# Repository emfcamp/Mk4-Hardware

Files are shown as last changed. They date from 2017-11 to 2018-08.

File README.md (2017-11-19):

Hardware
========

Hardware for the TiLDA Mkδ Badge for [Electromagnetic Field
2018](https://www.emfcamp.org).

Key Specs
---------
* TBD
*
*

License
-------
Copyright Electromagnetic Field Ltd. 2017

This documentation describes Open Hardware and is licensed under the
CERN OHL v. 1.2.  You may redistribute and modify this documentation
under the terms of the CERN OHL v.1.2. (http://ohwr.org/cernohl or the
LICENSE file in this repository). This documentation is distributed
WITHOUT ANY EXPRESS OR IMPLIED WARRANTY, INCLUDING OF MERCHANTABILITY,
SATISFACTORY QUALITY AND FITNESS FOR A PARTICULAR PURPOSE. Please see
the CERN OHL v.1.2 for applicable conditions.

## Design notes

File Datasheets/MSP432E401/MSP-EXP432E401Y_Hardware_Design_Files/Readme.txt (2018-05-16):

MSP-EXP432E401Y Hardware Design Files v1.00.00
Texas Instruments, Inc.

********************************************************************************
Welcome to the MSP-EXP432E401Y LaunchPad!
********************************************************************************

In this package, you will find hardware design files that can help you quickly
get started on developing your own project.

Available in the 'Hardware' folder are the complete board schematic and layout,
bill of material and Gerber files. This board was designed using Altium.

You can also find various web links in the 'Documentation' folder pointing to
the Tool Page, Quick Start Guide, and User's Guide.

For more resources, be sure to visit www.ti.com/tool/msp-exp432e401y

********************************************************************************
Revision History
********************************************************************************
Ver 1.00.00 - November 2nd, 2017
- Initial Release of Rev1.0 PCB

********************************************************************************
Project File Listing
********************************************************************************
|--Documentation                      : Folder containing links to more resources
|--Hardware                           : Folder containing hardware design files,
                                        bill of material and gerber files
|--Readme.txt                         : This file

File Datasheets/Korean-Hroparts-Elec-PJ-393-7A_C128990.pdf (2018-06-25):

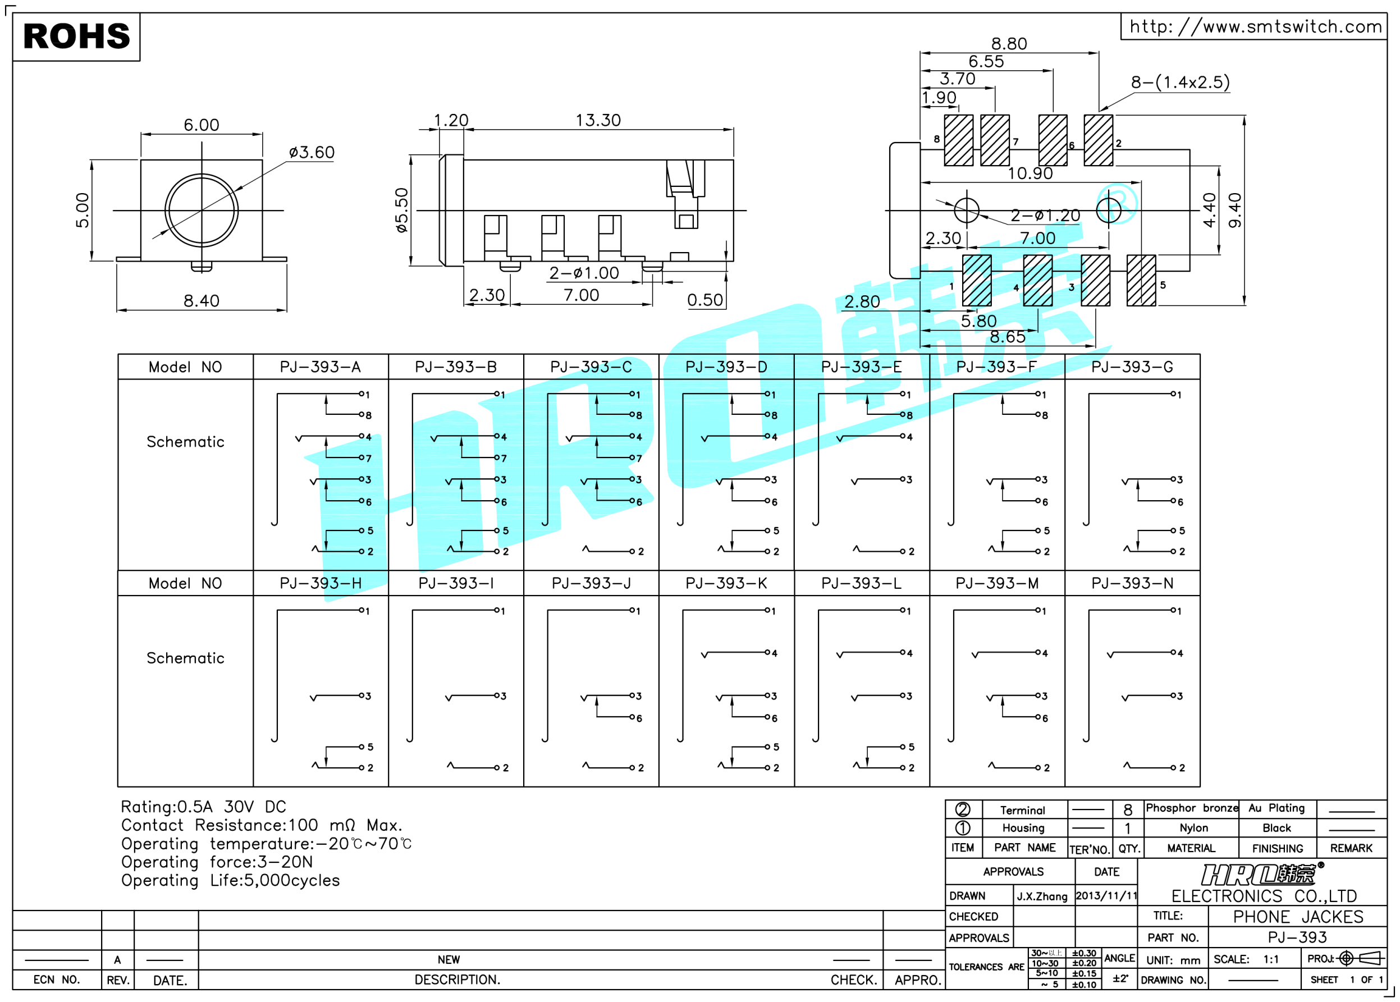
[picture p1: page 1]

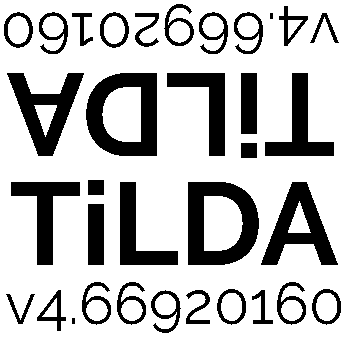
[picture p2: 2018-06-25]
Images/TiLDA v.466920160.bmp

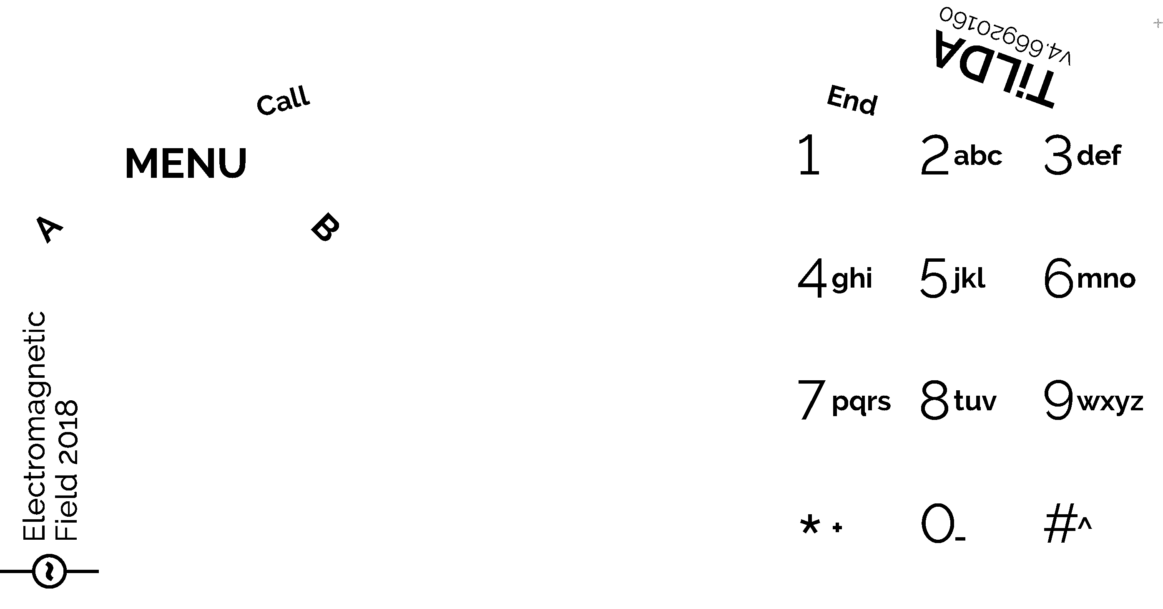
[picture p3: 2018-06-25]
Images/Mk4 Prototype a lwk.bmp

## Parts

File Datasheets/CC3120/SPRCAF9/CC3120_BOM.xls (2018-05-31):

Filename: | WCS001ABOM.xls
Variant: | None
Generated: | 11/30/2016 1:37:10 PM
 |  | CC3120-BOOST
Designator | Quantity | Value | Description | PackageReference | PartNumber | Manufacturer | Alternate PartNumber | Alternate Manufacturer
!PCB1 | 1 |  | Printed Circuit Board |  | WCS001 | Any | - | -
C1, C22, C24 | 3 | 10pF | CAP, CERM, 10 pF, 50 V, +/- 5%, C0G/NP0, 0402 | 0402 | 500R07S100JV4T | Johanson Technology
C2 | 1 | 0.5pF | CAP, CERM, 0.5 pF, 50 V, +/- 20%, C0G/NP0, 0402 | 0402 | GRM1555C1HR50BA01D | MuRata
C3, C5, C7, C8, C9, C10, C14, C15, C17, C18, C23, C27 | 12 | 0.1uF | CAP, CERM, 0.1 µF, 10 V, +/- 10%, X5R, 0402 | 0402 | C1005X5R1A104K050BA | TDK
C4, C16, C21 | 3 | 10uF | CAP, CERM, 10 µF, 6.3 V, +/- 20%, X5R, 0603 | 0603 | GRM188R60J106ME47D | MuRata
C6 | 1 | 1uF | CAP, CERM, 1 µF, 10 V, +/- 10%, X5R, 0402 | 0402 | C1005X5R1A105K050BB | TDK
C11, C12, C13 | 3 | 4.7uF | CAP, CERM, 4.7 µF, 6.3 V, +/- 20%, X5R, 0402 | 0402 | C1005X5R0J475M050BC | TDK
C19, C20 | 2 | 22uF | CAP, CERM, 22 µF, 4 V, +/- 20%, X5R, 0603 | 0603 | C1608X5R0G226M080AA | TDK
C25, C26 | 2 | 6.2pF | CAP, CERM, 6.2 pF, 50 V, +/- 5%, C0G/NP0, 0402 | 0402 | GRM1555C1H6R2CA01D | MuRata
C28 | 1 | 15pF | CAP, CERM, 15 pF, 50 V, +/- 5%, C0G/NP0, 0402 | 0402 | GRM1555C1H150JA01D | MuRata
C29, C32 | 2 | 10uF | CAP, CERM, 10 µF, 10 V, +/- 10%, X5R, 0805 | 0805 | GRM21BR61A106KE19L | MuRata
C30, C31 | 2 | 100uF | CAP, CERM, 100 µF, 6.3 V, +/- 20%, X5R, 1206 | 1206 | GRM31CR60J107ME39L | MuRata
C33 | 1 | 1000pF | CAP, CERM, 1000 pF, 50 V, +/- 10%, X5R, 0603 | 0603 | GRM188R61H102KA01D | MuRata
D1, D2 | 2 | 30V | Diode, Schottky, 30 V, 1 A, SOD-123 | SOD-123 | MBR130T1G | ON Semiconductor
D3 | 1 | Red | LED, Red, SMD | LED, 1.6x.8x.8mm | SML-311UTT86 | Rohm
D4 | 1 | Red | LED, Red, SMD | LED_0603 | 150060RS75000 | Wurth Elektronik
D5 | 1 | Green | LED, Green, SMD | LED_0603 | 150060GS75000 | Wurth Elektronik
D6 | 1 | Yellow | LED, Yellow, SMD | LED_0603 | 150060YS75000 | Wurth Elektronik eiSos
D7 | 1 | 45V | Diode, Schottky, 45 V, 0.03 A, 0603 Diode | 0603 Diode | CD0603-B00340 | Bourns
E1 | 1 |  | ANT BLUETOOTH W-LAN ZIGBEE WIMAX, SMD | 3.2x1.6mm | AH316M245001-T | Taiyo Yuden
FID1, FID2, FID3, FID4, FID5, FID6 | 6 |  | Fiducial mark. There is nothing to buy or mount. | Fiducial | N/A | N/A
FL1 | 1 | 1.02 dB | Multilayer Chip Band Pass Filter For 2.4GHz W-LAN/Bluetooth, SMD | 2x1.25mm | DEA202450BT-1294C1-H | TDK
J1 | 1 |  | Connector, Ultra-Mini Coaxial, SMD | Ultra small CO-AX SMD | U.FL-R-SMT-1 | Hirose Electric Co. Ltd.
J2 | 1 |  | Coaxial Connectors with Switch, 50 Ohm, SMD | Coaxial Connector with Switch | MM8030-2610RJ3 | MuRata
J4 | 1 |  | Header, 50mil, 3x2, Gold, TH | Header, 3x2, 1.27mm, TH | GRPB032VWVN-RC | Sullins Connector Solutions
J5 | 1 |  | Header, 50mil, 4x1, Gold, TH | TH, Header, 1.27 mm, 4x1, Straight | GRPB041VWVN-RC | Sullins Connector Solutions
J6 | 1 |  | Connector, Receptacle, Micro-USB Type B, R/A, Bottom Mount SMT | Micro USB receptacle | 105017-0001 | Molex
J7 | 1 |  | Header, 100mil, 3x1, Gold, TH | 3x1 Header | TSW-103-07-G-S | Samtec
J8 | 1 |  | Header, 100mil, 2x1, Gold, TH | Header, 2.54mm, 2x1, TH | HMTSW-102-07-G-S-240 | Samtec
L1 | 1 | 3.3nH | Inductor, Multilayer, Air Core, 3.3 nH, 0.3 A, 0.17 ohm, SMD | 0402 polarized | LQG15HS3N3S02D | MuRata
L2, L4 | 2 | 2.2uH | Inductor, Multilayer, Ferrite, 2.2 µH, 1.3 A, 0.08 ohm, SMD | SMD, Body 2.5x2mm, Height 1.2mm | LQM2HPN2R2MG0L | MuRata
L3 | 1 | 1uH | Inductor, Multilayer, Ferrite, 1 µH, 1.6 A, 0.055 ohm, SMD | SMD, Body 2.5x2mm, Height 1.2mm | LQM2HPN1R0MG0L | MuRata
L5, L6 | 2 | 30 ohm | Ferrite Bead, 30 ohm @ 100 MHz, 1.5 A, 0805 | 0805 | MMZ2012R300A | TDK
LBL1 | 1 |  | Thermal Transfer Printable Labels, 0.650" W x 0.200" H - 10,000 per roll | PCB Label 0.650"H x 0.200"W | THT-14-423-10 | Brady | - | -
P1, P2, P3, P4 | 4 |  | Connector, Receptacle, 100mil, 10x1, Gold plated, TH | 10x1 Receptacle | SSW-110-23-F-S | Samtec
Q1, Q2, Q3 | 3 | 50V | MOSFET, N-CH, 50 V, 0.22 A, SOT-23 | SOT-23 | BSS138 | Fairchild Semiconductor |  | None
R2, R12, R13, R17, R19, R21, R29, R30, R31, R32, R33, R34, R35, R36, R37, R39, R40, R41, R42, R43, R45, R46, R47 | 23 | 0 | RES, 0, 5%, 0.063 W, 0402 | 0402 | ERJ-2GE0R00X | Panasonic
R3, R56, R59, R60 | 4 | 10k | RES, 10 k, 5%, 0.063 W, 0402 | 0402 | CRCW040210K0JNED | Vishay-Dale
R4, R5, R6, R10 | 4 | 0 | RES, 0, 5%, 0.1 W, 0603 | 0603 | RC0603JR-070RL | Yageo America
R25 | 1 | 2.7k | 'RES, 2.7 k, 5%, 0.063 W, 0402 | 402 | CRCW04022K70JNED | 'Vishay-Dale
R7, R8, R9, R11, R14, R15, R16, R20, R23, R24, R26, R27, R52 | 13 | 100k | RES, 100 k, 5%, 0.063 W, 0402 | 0402 | CRCW0402100KJNED | Vishay-Dale
R18, R22, R38, R44 | 4 | 1.0k | RES, 1.0 k, 5%, 0.063 W, 0402 | 0402 | CRCW04021K00JNED | Vishay-Dale
R28 | 1 | 100k | RES, 100 k, 1%, 0.1 W, 0603 | 0603 | CRCW0603100KFKEA | Vishay-Dale
R48 | 1 | 0.1 | RES, 0.1, 1%, 0.25 W, 0805 | 0805 | CRM0805-FX-R100ELF | Bourns
R49, R54, R57 | 3 | 270 | RES, 270, 5%, 0.1 W, 0603 | 0603 | CRCW0603270RJNEA | Vishay-Dale
R50 | 1 | 51k | RES, 51 k, 5%, 0.063 W, 0402 | 0402 | CRCW040251K0JNED | Vishay-Dale
R51 | 1 | 30.1k | RES, 30.1 k, 1%, 0.063 W, 0402 | 0402 | CRCW040230K1FKED | Vishay-Dale
R53, R61, R62 | 3 | 100 | RES, 100, 1%, 0.1 W, 0402 | 0402 | ERJ-2RKF1000X | Panasonic
R55 | 1 | 0 | RES, 0, 5%, 0.1 W, 0603 | 0603 | ERJ-3GEY0R00V | Panasonic
R58 | 1 | 220 | RES, 220, 5%, 0.1 W, 0603 | 0603 | CRCW0603220RJNEA | Vishay-Dale
SW1 | 1 |  | Switch, Tactile, SPST-NO, SMT | Switch, 6.1x1.8x4.6 mm | EVQ-PSD02K | Panasonic
SW2, SW3 | 2 |  | Switch, SPST-NO, Off-Mom, 1 Pos, 0.05A, 12VDC, TH | 7.3x5.9mm | MJTP1117 | APEM
U1 | 1 |  | ULTRA LOW POWER, 16M-BIT [x 1/x 2/x 4] CMOS MXSMIO(SERIAL MULTI I/O) FLASH MEMORY, SOP-8 | 8-SOP | MX25R1635FM1IL0 | Macronix International Co., LTD
U2 | 1 |  | SimpleLink Wi-Fi Network Processor, Internet-of-Things Solution for MCU Applications, RGK0064B (VQFN-64) | RGK0064B | CC3120RNMARGKR | Texas Instruments | CC3120RNMARGKT | Texas Instruments
U3 | 1 |  | Ultralow-Noise, High PSRR, Fast, RF, 1A, Low-Dropout Linear Regulator, DCQ0006A | DCQ0006A | TPS79601DCQR | Texas Instruments |  | Texas Instruments
Y1 | 1 |  | CRYSTAL, 32.768KHZ, 9PF, SMD | 3.2x0.9x1.5mm | ABS07-32.768KHZ-9-T | Abracon Corportation
Y2 | 1 |  | Low Power Clock Oscillator, 32.768 kHz, SMD | OSC, 1.5x1x3.2mm | OV-7604-C7 | Micro Crystal AG
Y3 | 1 |  | Crystal, 40MHz, 8pF, SMD | 2.5x2mm | Q24FA20H0039600 | Epson
 |  | Notes:
 |  | Unless otherwise noted in the Alternate PartNumber and/or Alternate Manufacturer columns, all parts may be substituted with equivalents.

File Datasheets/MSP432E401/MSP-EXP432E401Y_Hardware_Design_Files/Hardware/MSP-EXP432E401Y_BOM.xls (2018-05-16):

Filename: | MCU0231.0(001)_BOM.xls
Variant: | 001
Generated: | 10/3/2017 2:07:19 PM
 |  | MSP-EXP432E401Y
Designator | Quantity | Value | Description | PackageReference | PartNumber | Manufacturer | Alternate PartNumber | Alternate Manufacturer
!PCB | 1 |  | Printed Circuit Board |  | MCU023 | Any | - | -
C1 | 1 | 1000pF | CAP, CERM, 1000 pF, 2000 V, +/- 10%, X7R, 1210 | 1210 | C1210C102KGRACTU | Kemet
C3, C4, C16, C17, C18, C22, C23, C24, C25, C26, C27, C28, C29, C30, C40, C41, C42, C43, C46 | 19 | 0.1uF | CAP, CERM, 0.1 µF, 16 V, +/- 10%, X7R, 0402 | 0402 | GRM155R71C104KA88D | MuRata
C14, C140, C142, C144 | 4 | 1uF | CAP, CERM, 1 µF, 10 V, +/- 10%, X5R, 0402 | 0402 | GRM155R61A105KE15D | MuRata
C15 | 1 | 2.2uF | CAP, CERM, 2.2 µF, 16 V, +/- 10%, X5R, 0603 | 0603 | GRM188R61C225KE15D | MuRata
C31 | 1 | 4700pF | CAP, CERM, 4700 pF, 2000 V, +/- 10%, X7R, 1812 | 1812 | 1812GC472KAT1A | AVX
C32 | 1 | 3300pF | CAP, CERM, 3300 pF, 50 V, +/- 10%, X7R, 0603 | 0603 | GRM188R71H332KA01D | MuRata
C44, C45, C47, C48, C133, C134 | 6 | 12pF | CAP, CERM, 12 pF, 50 V, +/- 5%, C0G/NP0, 0402 | 0402 | GRM1555C1H120JA01D | MuRata
C102 | 1 | 3300pF | CAP, CERM, 3300 pF, 50 V, +/- 10%, X7R, 0402 | 0402 | GRM155R71H332KA01D | MuRata
C132, C138, C139, C143, C146 | 5 | 0.1uF | CAP, CERM, 0.1 µF, 6.3 V, +/- 10%, X7R, 0402 | 0402 | GRM155R70J104KA01D | MuRata
C135, C136, C137, C141, C150, C159 | 6 | 0.01uF | CAP, CERM, 0.01 µF, 25 V, +/- 10%, X7R, 0402 | 0402 | GRM155R71E103KA01D | MuRata
C145, C148, C149 | 3 | 2.2uF | CAP, CERM, 2.2 µF, 6.3 V, +/- 10%, X5R, 0402 | 0402 | GRM155R60J225KE95D | MuRata
C147 | 1 | 15pF | CAP, CERM, 15 pF, 50 V, +/- 5%, C0G/NP0, 0402 | 0402 | GRM1555C1H150JA01D | MuRata
D1, D2, D3, D4, LED101 | 5 | Green | LED, Green, SMD | 1.6x0.8x0.8mm | LTST-C190GKT | Lite-On
IC6 | 1 |  | Precision Micropower Shunt Voltage Reference, 0.2% accuracy, 2.5 V, 15 ppm / degC, 15 mA, -40 to 85 degC, 5-pin SC70 (DCK), Green (RoHS & no Sb/Br) | DCK0005A | LM4040B25IDCKRA | Texas Instruments | Equivalent | Texas Instruments
IC101 | 1 |  | Single Output High PSRR LDO, 1 A, Adjustable 1.2 to 5.5 V Output, 2.7 to 5.5 V Input, 8-pin SON (DRB), -40 to 125 degC, Green (RoHS & no Sb/Br) | DRB0008B | TPS79601DRBR | Texas Instruments | Equivalent | Texas Instruments
IC102 | 1 |  | ESD-Protection Array for High-Speed Data Interfaces, 4 Channels, -40 to +85 degC, 6-pin SON (DRY), Green (RoHS & no Sb/Br) | DRY0006A | TPD4E004DRYR | Texas Instruments | Equivalent | Texas Instruments
IC106 | 1 |  | IoT enabled High performance 32-bit ARM(R) Cortex(R)-M4F based MCU, PDT0128A (TQFP-128) | PDT0128A | TM4C129ENCPDTI3R | Texas Instruments | TM4C129ENCPDTI3 | Texas Instruments
J1/J3, J2/J4, J5/J7, J6/J8 | 4 |  | Receptacle, 2.54mm, 10x2, Tin, TH | 10x2 Receptacle | SSQ-110-03-T-D | Samtec | CRD-081413-A-G | Major League Electronics
J11, J102 | 2 |  | Header (Shrouded), 1.27mm, 5x2, Gold, SMT | Header(Shrouded), 1.27mm, 5x2, SMT | FTSH-105-01-F-DV-K | Samtec
J12, J13 | 2 |  | Header, 100mil, 3x1, Tin, TH | Header, 3 PIN, 100mil, Tin | PEC03SAAN | Sullins Connector Solutions
J101 | 1 |  | Header, 2.54mm, 10x2, Tin, TH | Header, 10x2, 2.54mm, TH | PEC10DAAN | Sullins Connector Solutions
JP1 | 1 |  | Header, 100mil, 3x2, Tin, TH | 3x2 Header | PEC03DAAN | Sullins Connector Solutions
JP2, JP6, JP7 | 3 |  | Header, 100mil, 2x1, Tin, TH | Header, 2 PIN, 100mil, Tin | PEC02SAAN | Sullins Connector Solutions
JP4, JP5 | 2 |  | Header, 2.54mm, 2x2, Gold, TH | Header, 2.54mm, 2x2, TH | PBC02DAAN | Sullins Connector Solutions
LED102 | 1 | Red | LED, Red, SMD | Red LED, 1.6x0.8x0.8mm | LTST-C190CKT | Lite-On
Q101 | 1 |  | Crystal, 16MHz, 8pF, SMD | 3.2x0.75x2.5mm | NX3225GA-16.000M-STD-CRG-1 | NDK
R1, R2, R35, R44, R50, R117 | 6 | 10k | RES, 10 k, 5%, 0.063 W, 0402 | 0402 | CRCW040210K0JNED | Vishay-Dale
R4, R39, R41 | 3 | 0 | RES, 0, 5%, 0.063 W, 0402 | 0402 | ERJ-2GE0R00X | Panasonic
R18, R51, R120, R166 | 4 | 100 | RES, 100, 5%, 0.063 W, 0402 | 0402 | CRCW0402100RJNED | Vishay-Dale
R21, R22, R23, R24 | 4 | 49.9 | RES, 49.9, 1%, 0.063 W, 0402 | 0402 | CRCW040249R9FKED | Vishay-Dale
R25, R128 | 2 | 4.87k | RES, 4.87 k, 1%, 0.063 W, 0402 | 0402 | CRCW04024K87FKED | Vishay-Dale
R26, R36 | 2 | 100k | RES, 100 k, 5%, 0.063 W, 0402 | 0402 | CRCW0402100KJNED | Vishay-Dale
R27, R30, R31, R33 | 4 | 390 | RES, 390, 5%, 0.063 W, 0402 | 0402 | CRCW0402390RJNED | Vishay-Dale
R32, R43, R45, R46 | 4 | 75 | RES, 75, 5%, 0.063 W, 0402 | 0402 | CRCW040275R0JNED | Vishay-Dale
R38, R131 | 2 | 51 | RES, 51, 5%, 0.063 W, 0402 | 0402 | CRCW040251R0JNED | Vishay-Dale
R42 | 1 | 1.0Meg | RES, 1.0 M, 5%, 0.063 W, 0402 | 0402 | CRCW04021M00JNED | Vishay-Dale
R47 | 1 | 1.0Meg | RES, 1.0 M, 5%, 0.25 W, 1206 | 1206 | CRCW12061M00JNEA | Vishay-Dale
R49 | 1 | 2.0k | RES, 2.0 k, 5%, 0.063 W, 0402 | 0402 | CRCW04022K00JNED | Vishay-Dale
R52 | 1 | 1.0Meg | RES, 1.0 M, 5%, 0.1 W, 0603 | 0603 | CRCW06031M00JNEA | Vishay-Dale
R101, R102 | 2 | 0 | RES, 0, 5%, 0.1 W, 0603 | 0603 | CRCW06030000Z0EA | Vishay-Dale
R108, R109, R110, R111, R118 | 5 | 1.0k | RES, 1.0 k, 5%, 0.063 W, 0402 | 0402 | CRCW04021K00JNED | Vishay-Dale
R122 | 1 | 330k | RES, 330 k, 1%, 0.0625 W, 0402 | 0402 | RC0402FR-07330KL | Yageo America
R123, R125 | 2 | 470 | RES, 470, 1%, 0.1 W, AEC-Q200 Grade 0, 0402 | 0402 | ERJ-2RKF4700X | Panasonic
R124 | 1 | 220k | RES, 220 k, 1%, 0.0625 W, 0402 | 0402 | RC0402FR-07220KL | Yageo America
R132 | 1 | 1.00Meg | RES, 1.00 M, 1%, 0.063 W, 0402 | 0402 | CRCW04021M00FKED | Vishay-Dale
R133 | 1 | 51k | RES, 51 k, 5%, 0.063 W, 0402 | 0402 | CRCW040251K0JNED | Vishay-Dale
R134 | 1 | 30k | RES, 30 k, 5%, 0.063 W, 0402 | 0402 | CRCW040230K0JNED | Vishay-Dale
R158 | 1 | 3.3k | RES, 3.3 k, 5%, 0.063 W, 0402 | 0402 | CRCW04023K30JNED | Vishay-Dale
RESET_SW1, USR_SW1, USR_SW2, Wake_SW4 | 4 |  | Switch, SPST, 0.05 A, 12 VDC, SMD | 7.8x3.5mm | 1188E-1K2-V-TR | Diptronics
SH-J101A, SH-J101B, SH-J101C, SH-J101D, SH-J101E, SH-J101F, SH-J101G, SH-J101H, SH-J101I, SH-J101J, SH-JP1, SH-JP2, SH-JP4A, SH-JP4B, SH-JP5A, SH-JP5B, SH-JP6, SH-JP7 | 18 | 1x2 | Shunt, 100mil, Gold plated, Black | Shunt | SNT-100-BK-G | Samtec | 969102-0000-DA | 3M
U1 | 1 |  | IoT enabled High performance 32-bit ARM(R) Cortex(R)-M4F based MCU, PDT0128A (TQFP-128) | PDT0128A | MSP432E401YTPDTR | Texas Instruments
U2 | 1 |  | USB ESD Solution with Power Clamp, 4 Channels, -40 to +85 degC, 6-pin SON (DRY), Green (RoHS & no Sb/Br) | DRY0006A | TPD4S012DRYR | Texas Instruments | Equivalent | Texas Instruments
U4 | 1 |  | Current-Limited, Power-Distribution Switches, DRB0008B (VSON-8) | DRB0008B | TPS2052BDRBR | Texas Instruments | TPS2052BDRBT | Texas Instruments
U7 | 1 |  | Connector, Receptacle, Micro-USB Type AB, R/A, Bottom Mount SMT | Connector, Receptacle, Micro-USB Type AB, R/A, Bottom Mount SMT | ZX62D-AB-5P8 | Hirose Electric Co. Ltd.
U8, U108 | 2 |  | Low-Capacitance + / - 15 kV ESD Protection Array for High-Speed Data Interfaces, 6 Channels, -40 to +85 degC, 8-pin UQFN (RSE), Green (RoHS & no Sb/Br) | RSE0008A | TPD6E004RSER | Texas Instruments | Equivalent | Texas Instruments
U10 | 1 | 350uH | Transformer, 350 uH, SMT | 12.7x9.09mm | HX1198FNLT | Pulse Engineering
U13 | 1 | 2.8V | Diode, TVS, Uni, 2.8 V, 15 Vc, SOIC-8 | SOIC-8 | SLVU2.8-4.TBT | Semtech
U14 | 1 |  | RJ-45, No LED, tab up, R/A, TH | 16.26x14.54x15.75 | 1-406541-1 | TE Connectivity
USB101 | 1 |  | Receptacle, USB 2.0, Micro B, 5 Position, R/A, SMT | Receptacle, USB 2.0, Micro B, 5 Pos, 0.65mm Pitch, R/A, SMT | 1051640001 | Molex
USB_Cable | 1 |  | Cable, USB-A to micro USB-B, 0.3 m |  | AK67421-0.3 | Assman WSW
Y1 | 1 |  | Crystal, 25 MHz, 8pF, SMD | 3.2x0.75x2.5mm | NX3225GA-25.000M-STD-CRG-2 | NDK
Y3 | 1 |  | Crystal, 32.768 MHz, SMD | D1.9xL6mm | CMR200T-32.768KDZY-UT | Citizen Finetech Miyota
BSL | 0 |  | Header(Shrouded), 2.54mm, 5x2, Gold, TH | Header, 2.54mm, 5x2, TH | AWHW-10G-0202-T | Assman WSW
J10 | 0 |  | Header, 2.54mm, 49x2, Gold, TH | Header, 2.54mm, 49x2, TH | TSW-149-07-S-D | Samtec
R3, R5, R6, R7, R8, R9, R10, R11, R12, R19, R20 | 0 | 0 | RES, 0, 5%, 0.063 W, 0402 | 0402 | ERJ-2GE0R00X | Panasonic
R13, R14 | 0 | 3.3k | RES, 3.3 k, 5%, 0.063 W, 0402 | 0402 | CRCW04023K30JNED | Vishay-Dale
R121 | 0 | 10K | RES, 10 k, 5%, 0.063 W, 0402 | 0402 | CRCW040210K0JNED | Vishay-Dale
TP4, TP5, TP6, TP7, TP8, TP9, TP10, TP11, TP12, TP13, TP14, TP15, TP16, TP17 | 0 | Black | Test Point, Miniature, Black, TH | Black Miniature Testpoint | 5001 | Keystone
 |  | Notes:
 |  | Unless otherwise noted in the Alternate PartNumber and/or Alternate Manufacturer columns, all parts may be substituted with equivalents.

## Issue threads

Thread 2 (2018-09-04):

Cannot checkout repo on Windows

csBlueChip, 2018-09-04:
...because of this filename:
Mk4-Hardware/Datasheets/704060 2000mAh 3.7V Specific ation For Appro val???? ????.pdf

Proposed fix : remove '?' chars from filename

Closed 2018-09-09.

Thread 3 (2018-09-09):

Ethernet termination / pull-up resistors missing

jburgess777, 2018-09-09:
The technical reference manual (SLAU723) has an example of the typical Ethernet design in Figure 15-15. "Interface to Ethernet Jack". This shows four 49.9 ohm resistors pulling up to 3v3 on each of the Ethernet transmit (EN0TXOP/EN0TXON) and receive pairs (EN0RXIP/EN0RXIN). As far as I can tell, these seem to have been omitted on TilDa Mk4 board. This could explain problems in getting the port to link.

Another possible problem is that the RBIAS resistor on the schematic is shown as 4.87kR 5% but the TRM shows 1%.

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

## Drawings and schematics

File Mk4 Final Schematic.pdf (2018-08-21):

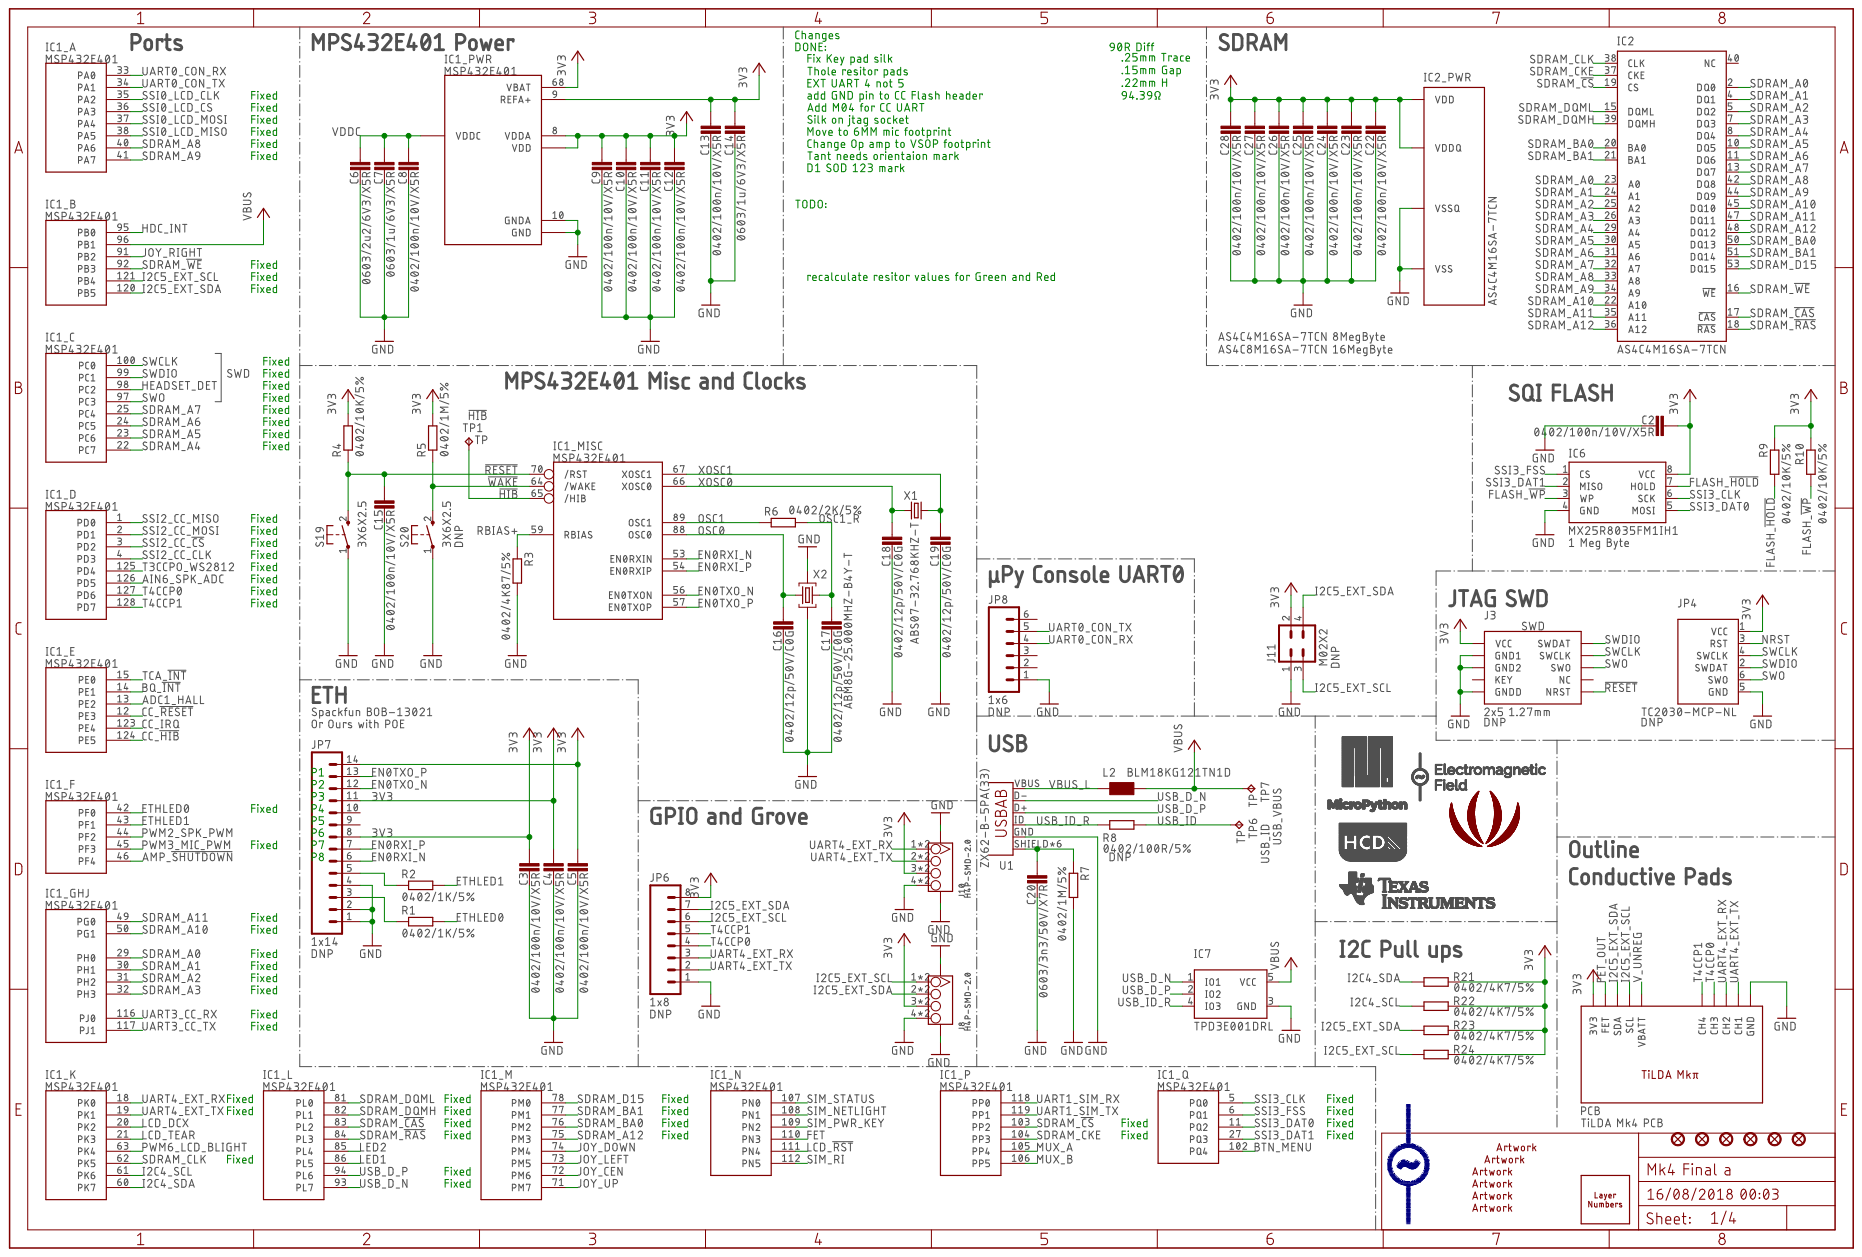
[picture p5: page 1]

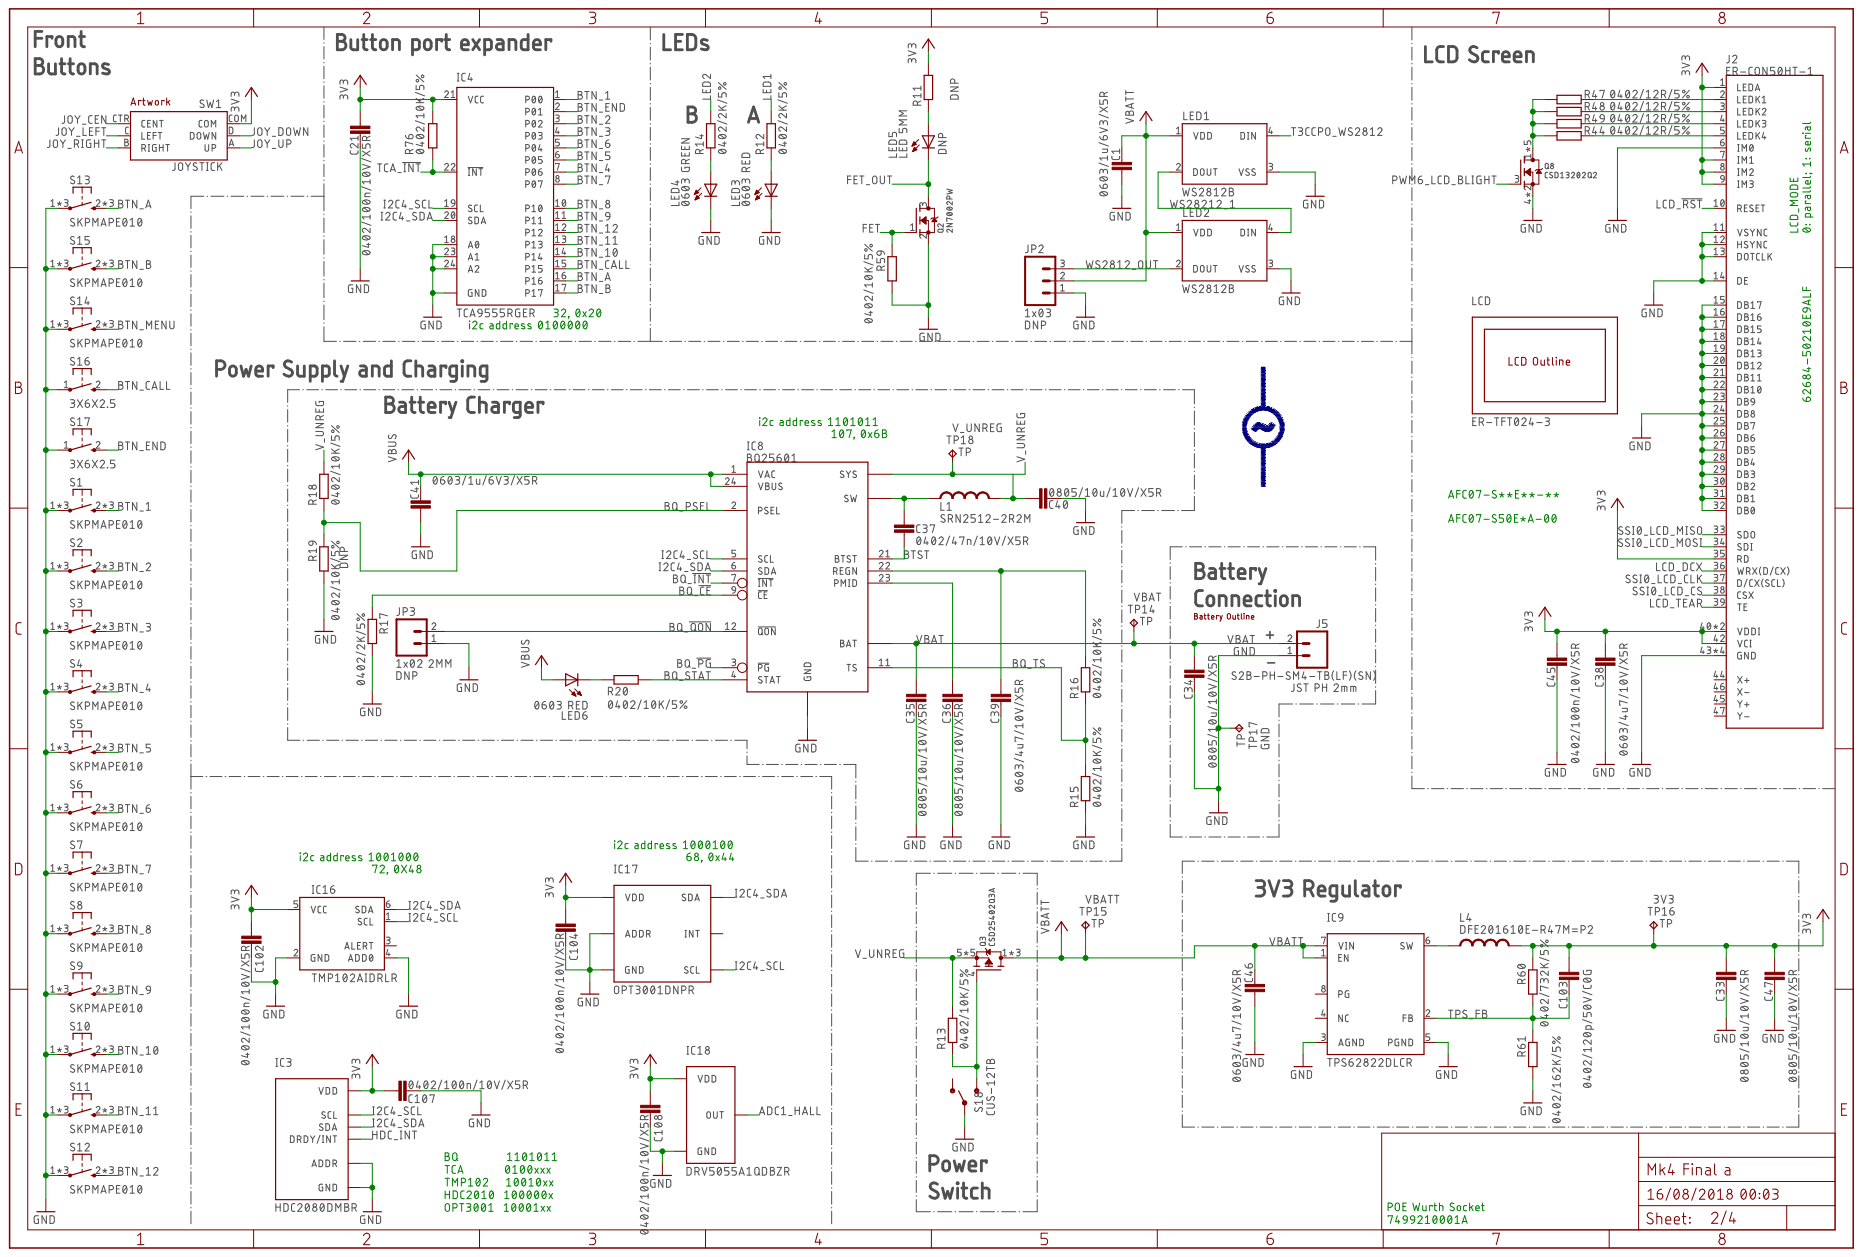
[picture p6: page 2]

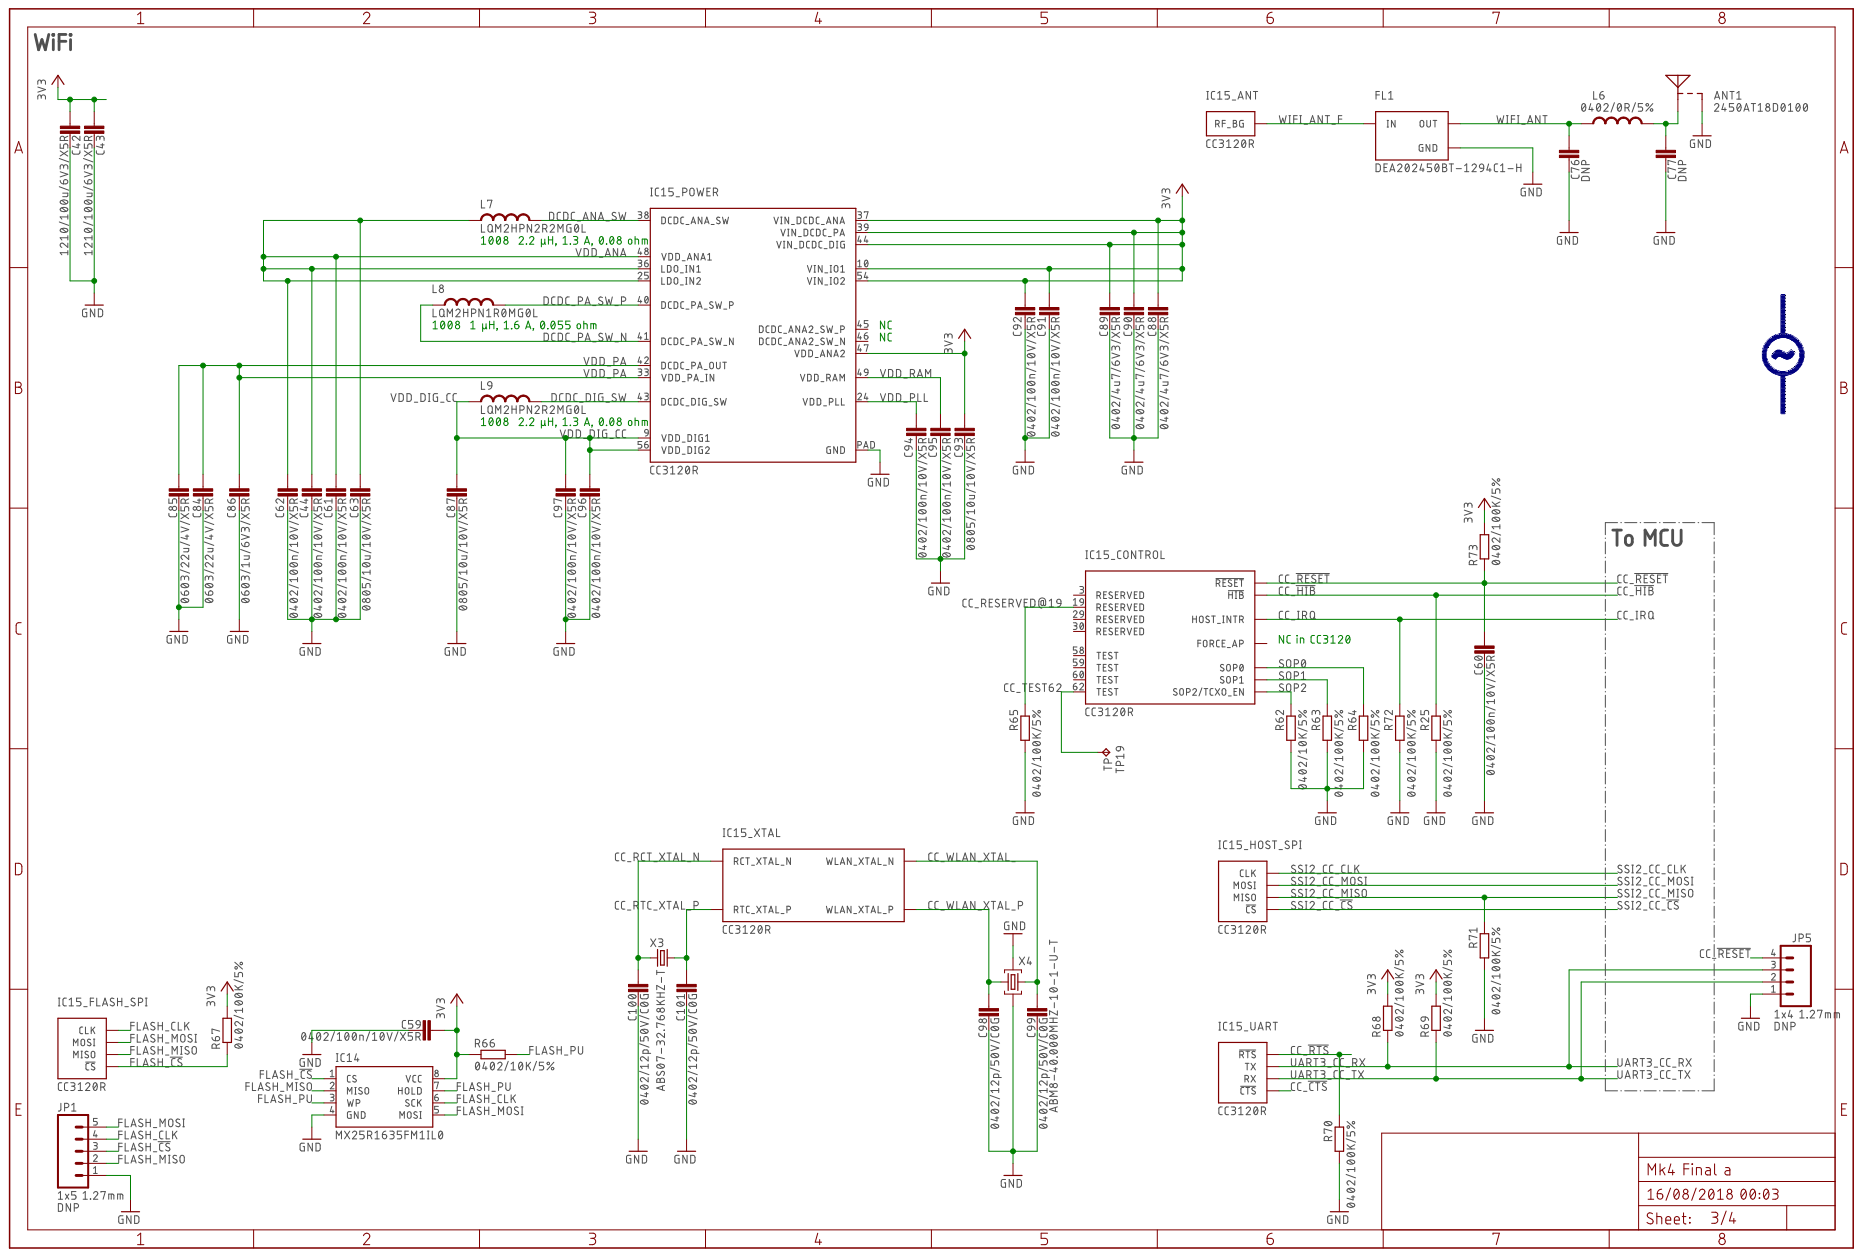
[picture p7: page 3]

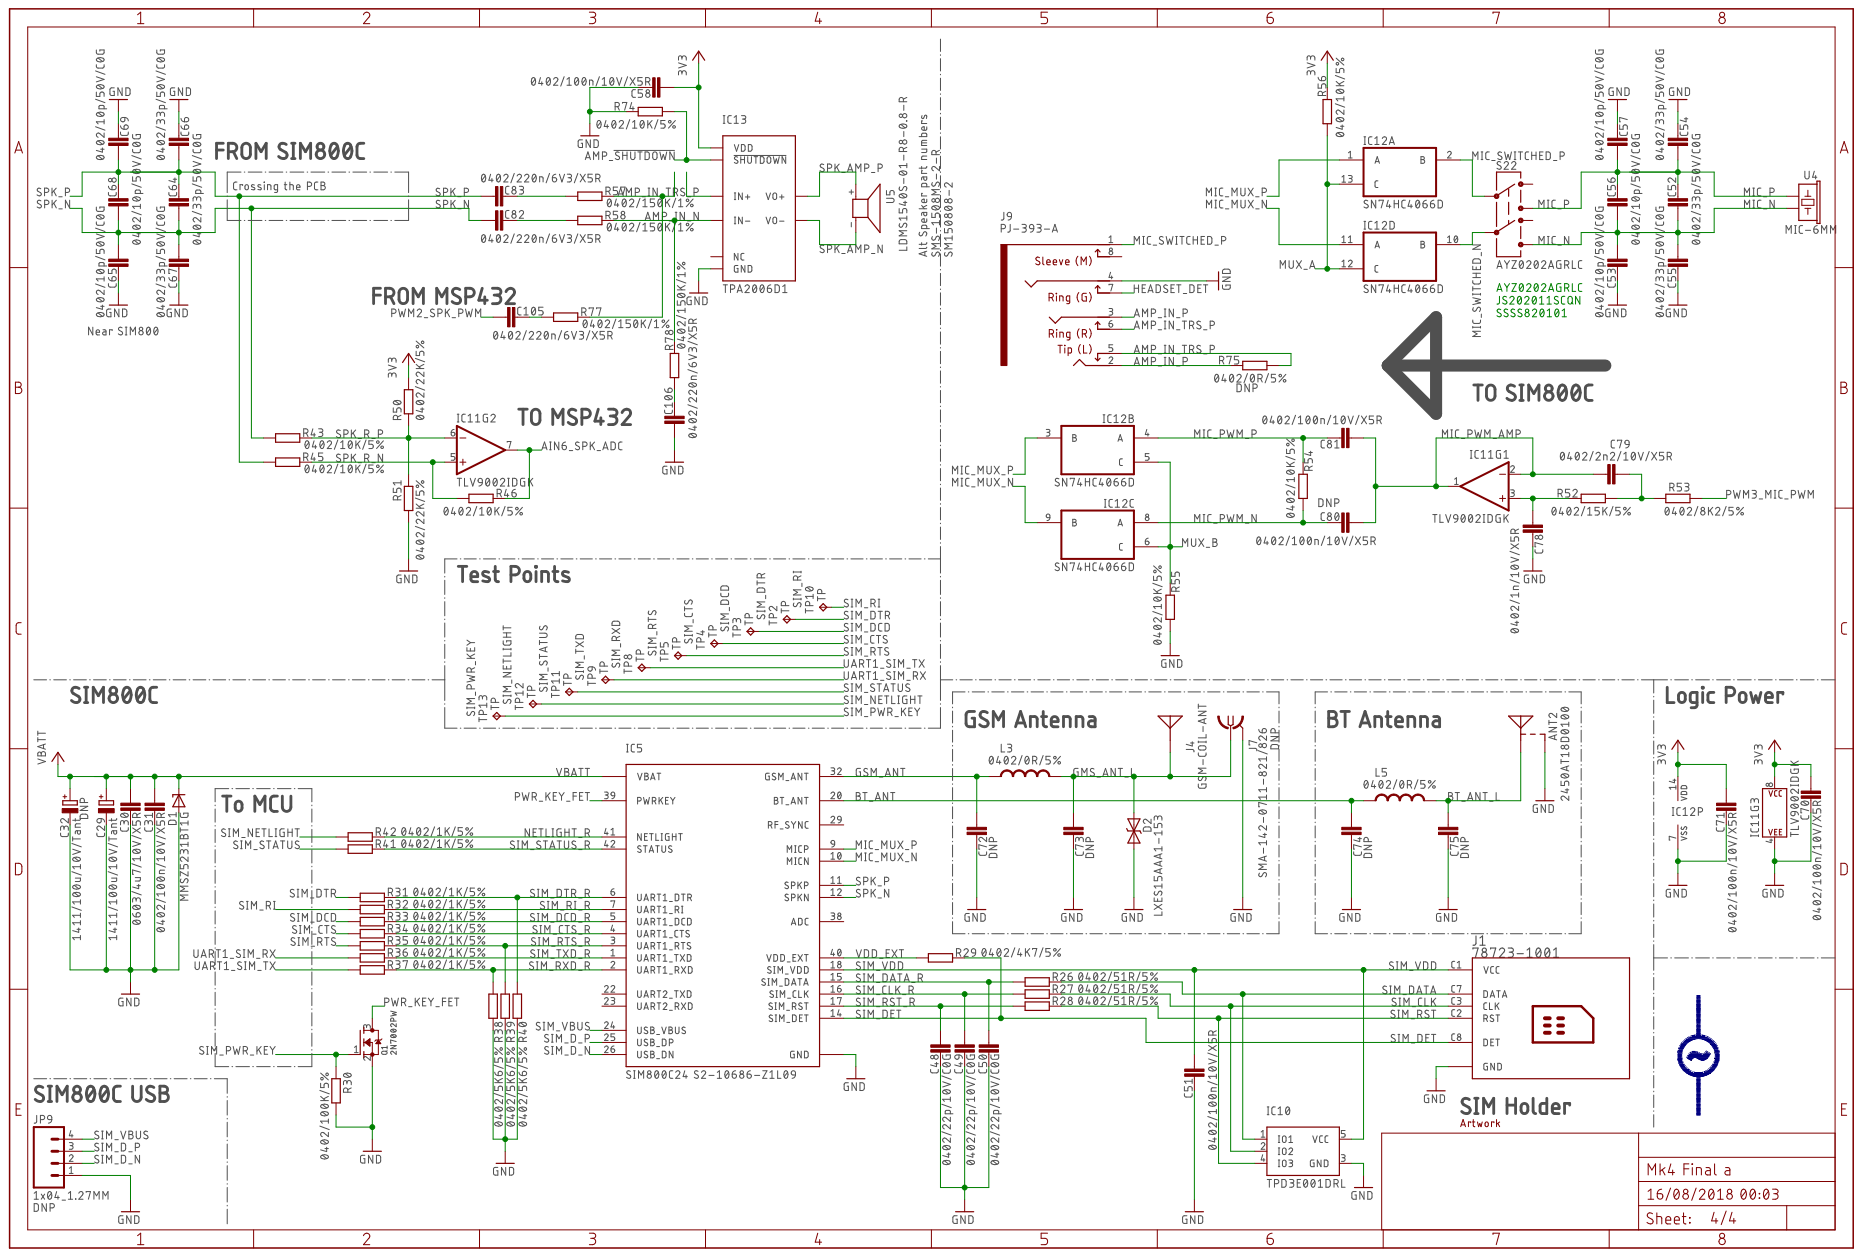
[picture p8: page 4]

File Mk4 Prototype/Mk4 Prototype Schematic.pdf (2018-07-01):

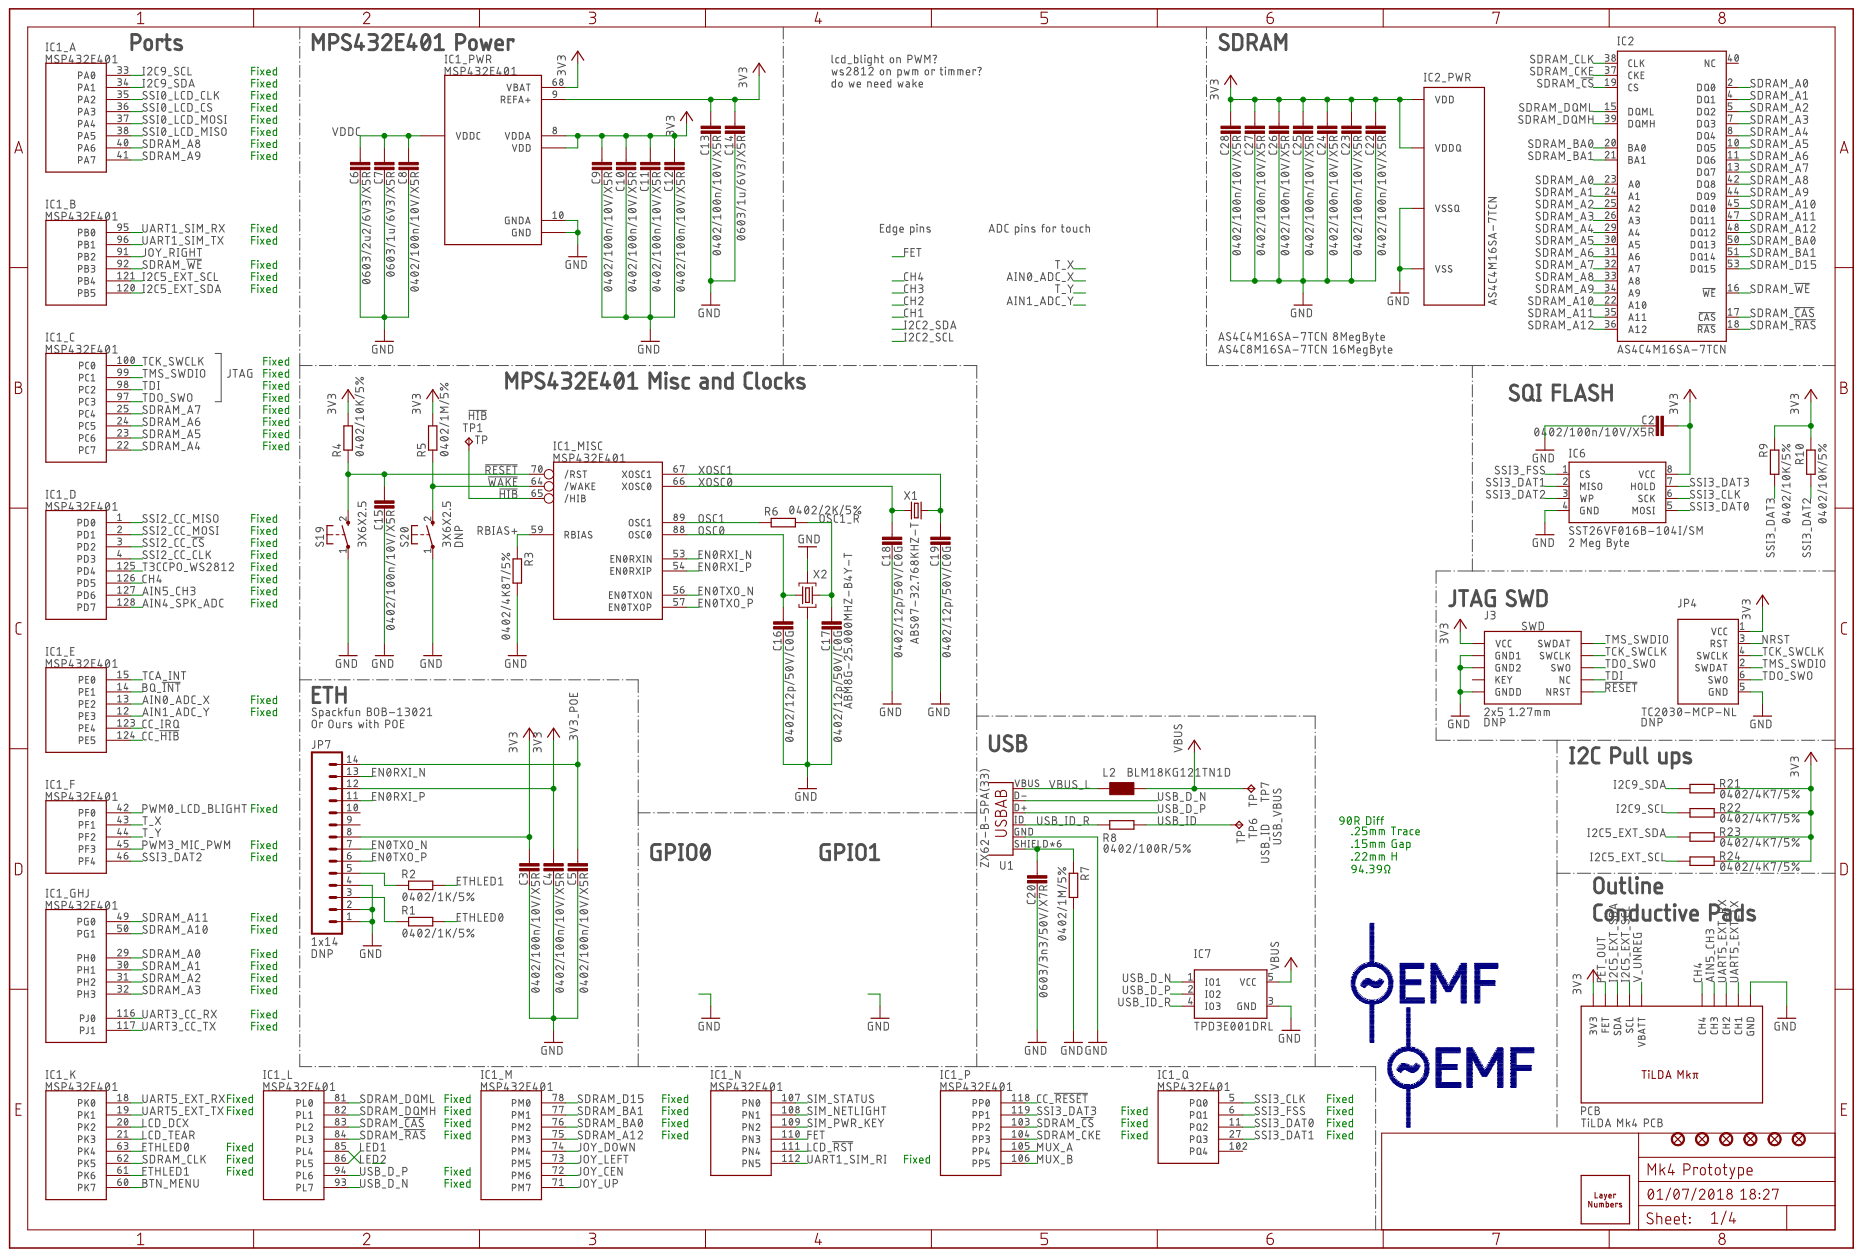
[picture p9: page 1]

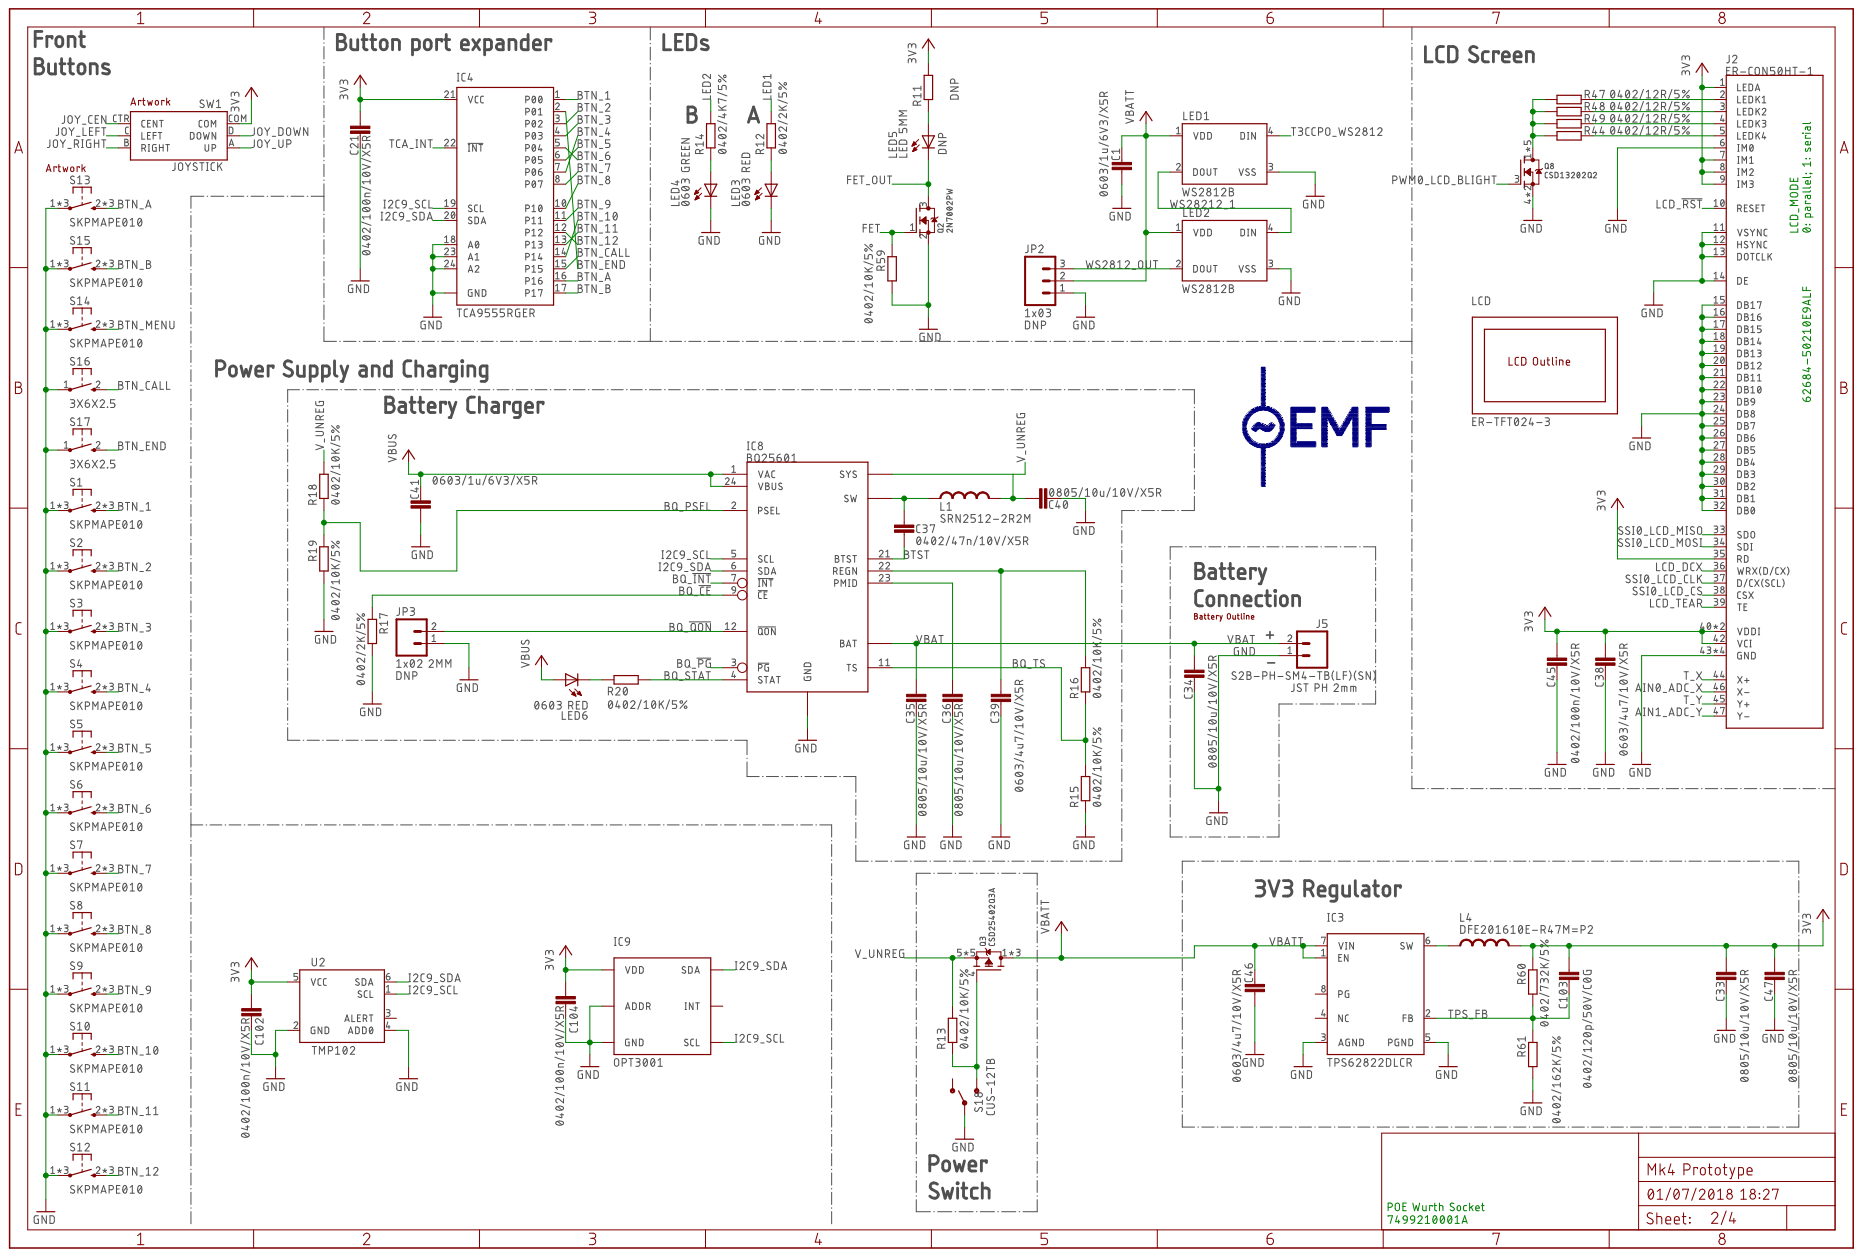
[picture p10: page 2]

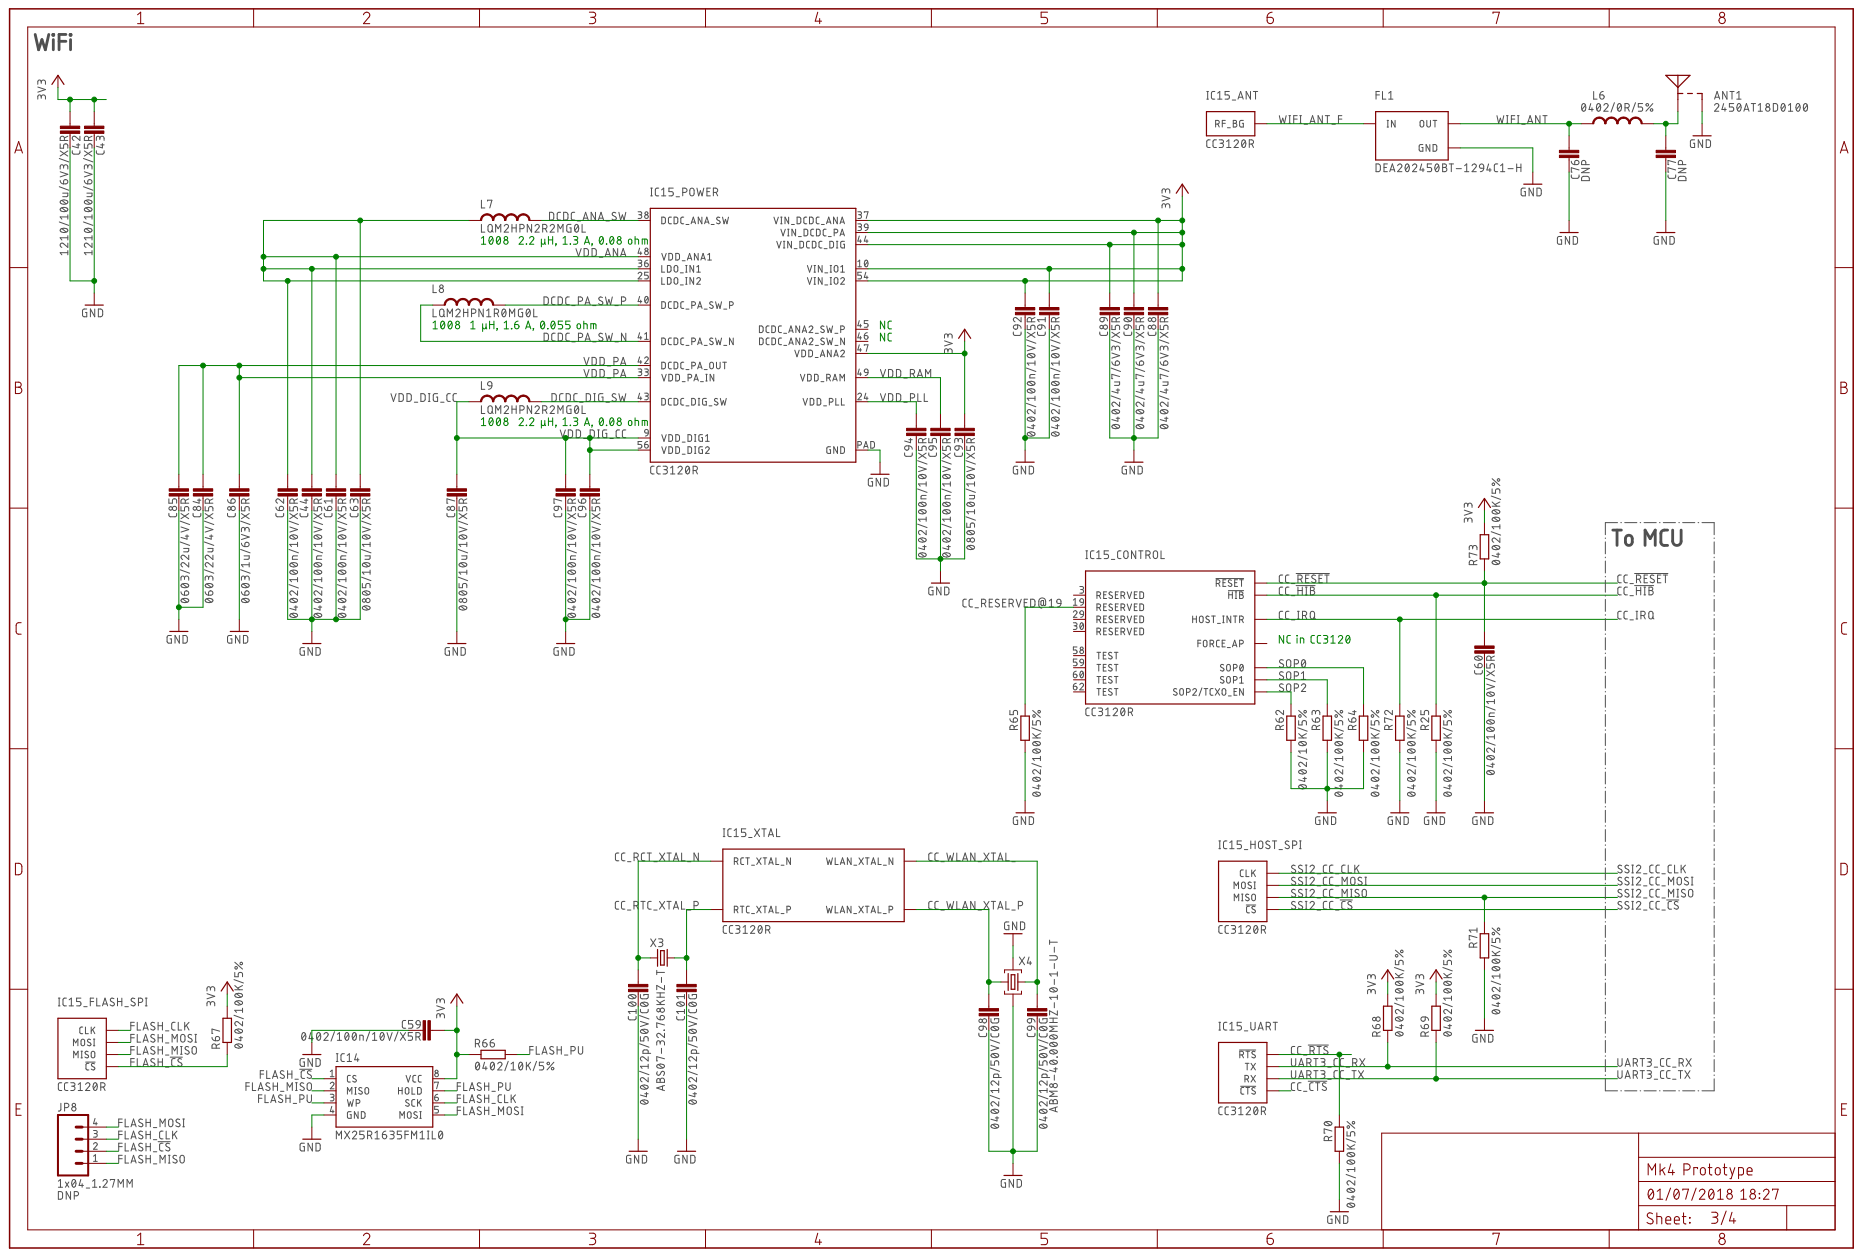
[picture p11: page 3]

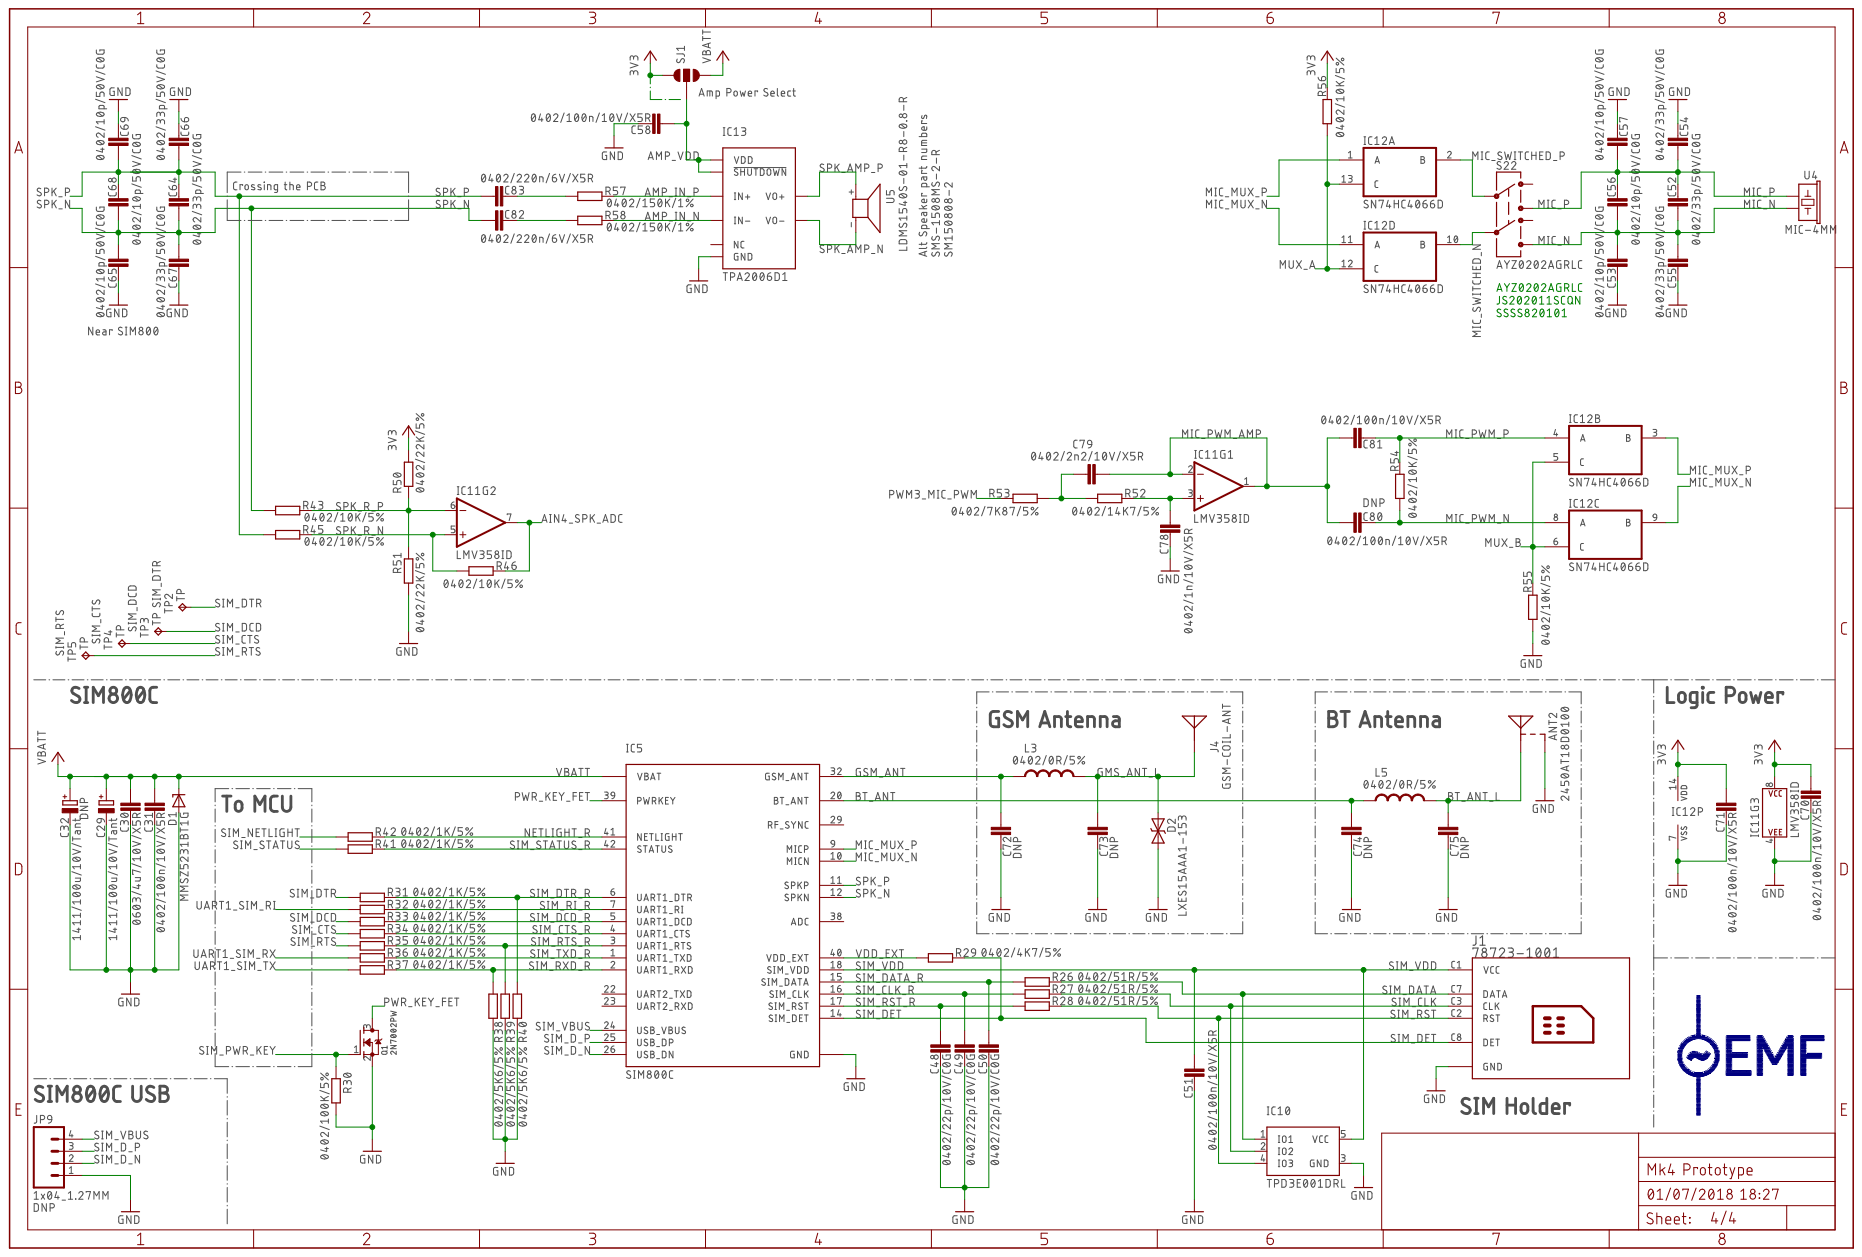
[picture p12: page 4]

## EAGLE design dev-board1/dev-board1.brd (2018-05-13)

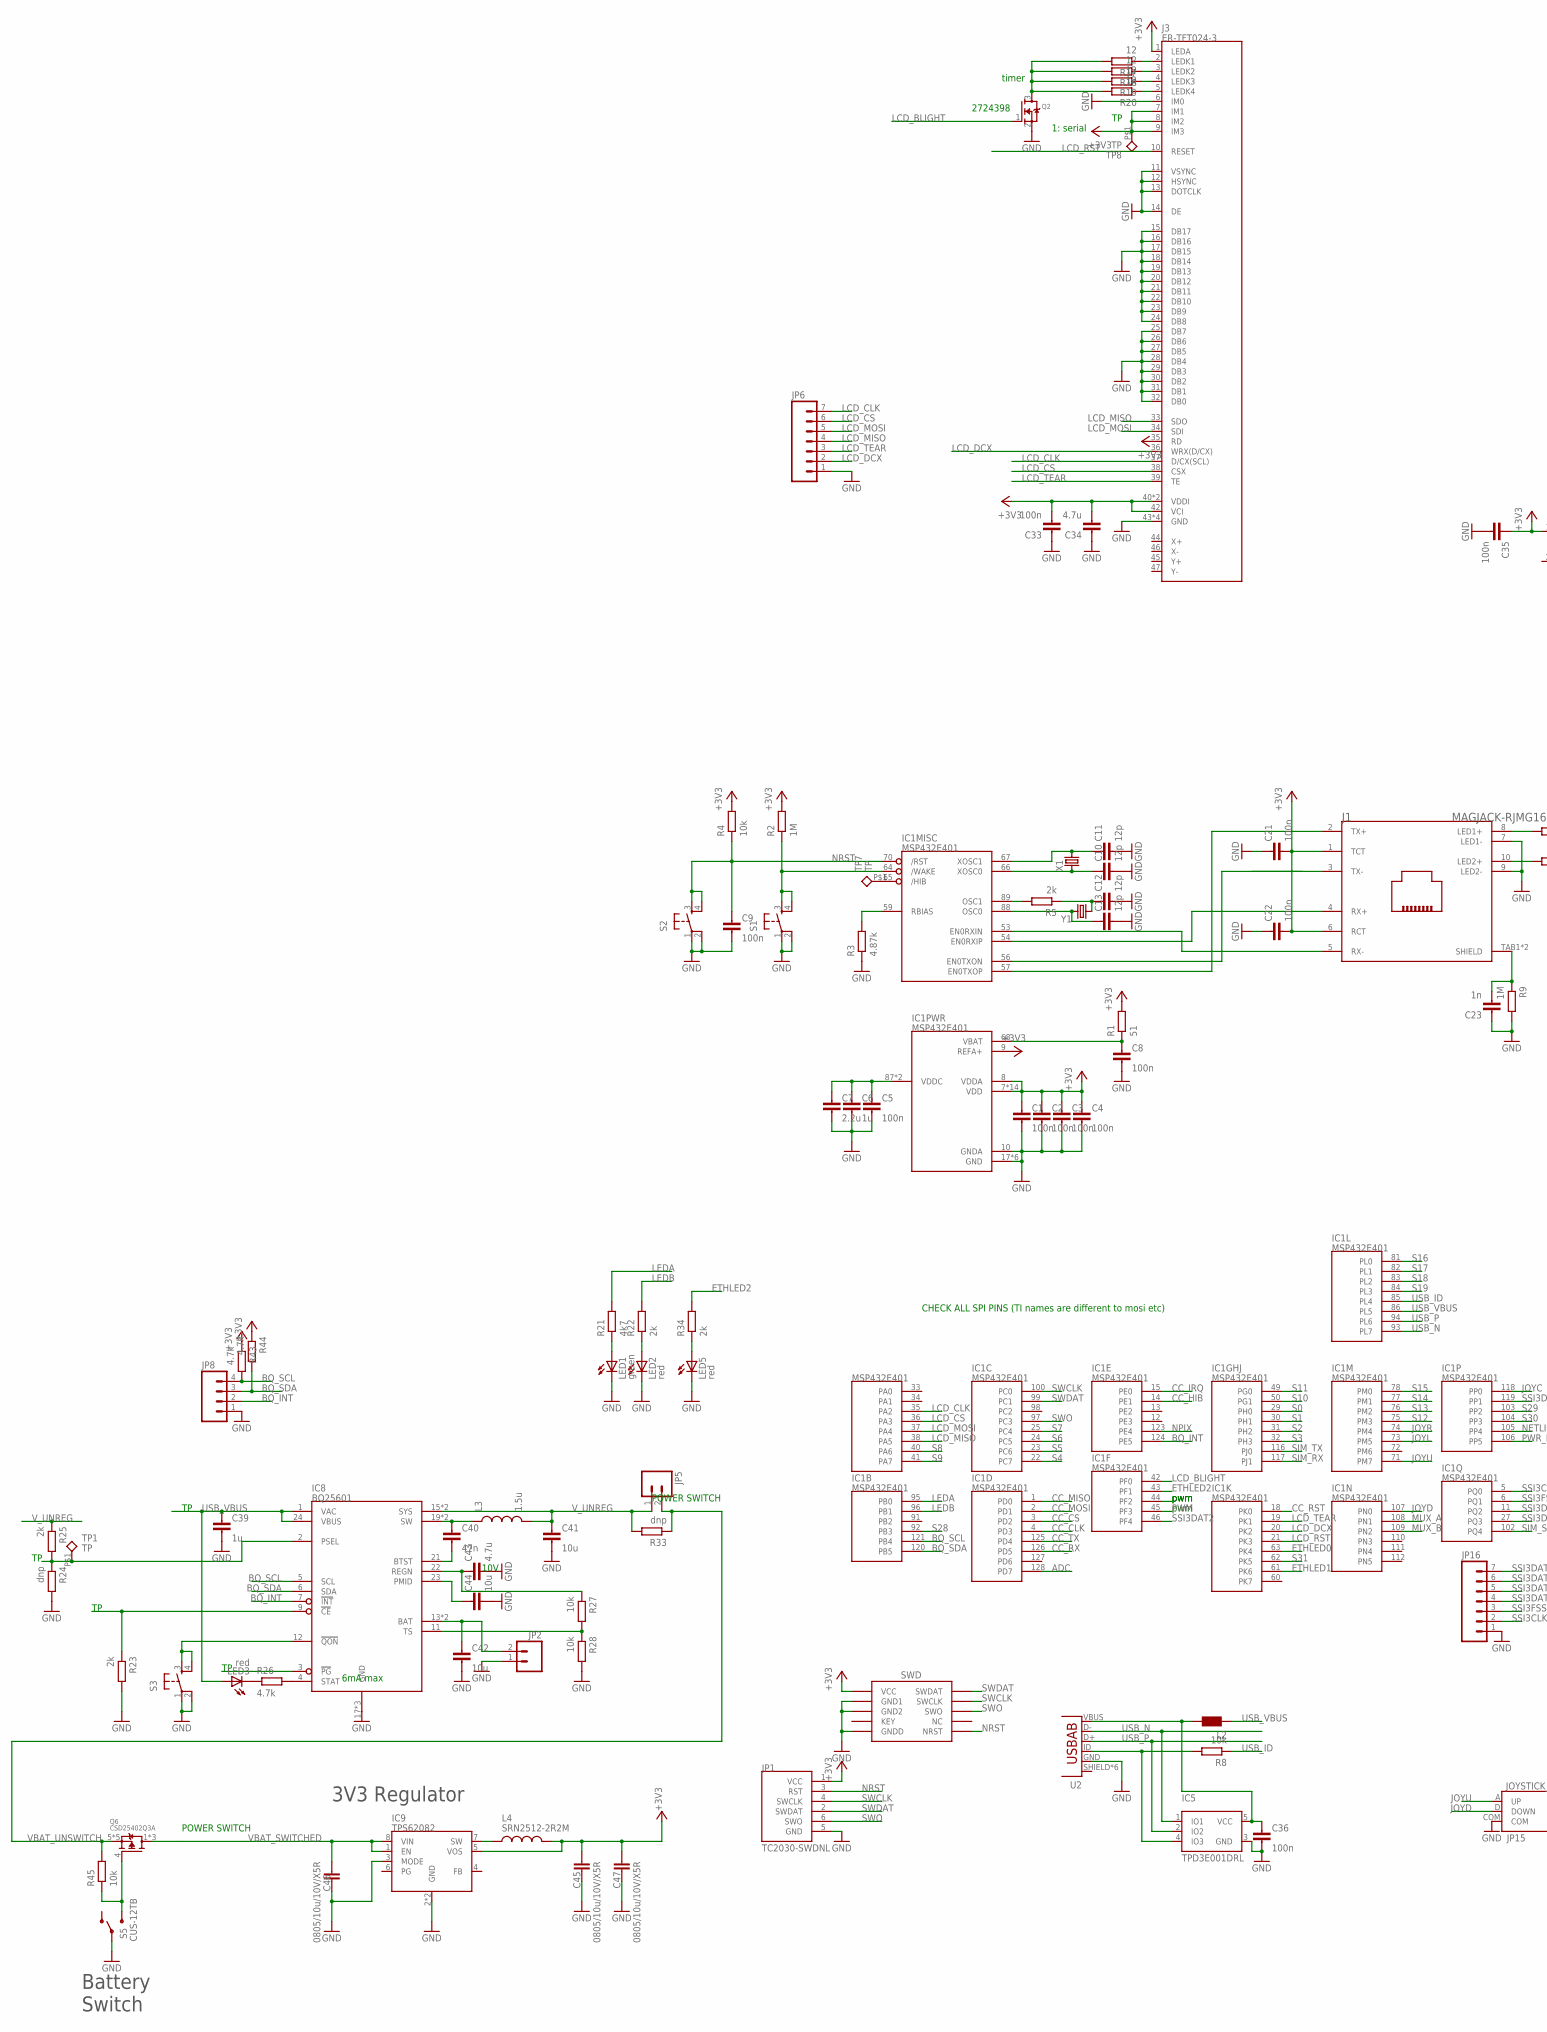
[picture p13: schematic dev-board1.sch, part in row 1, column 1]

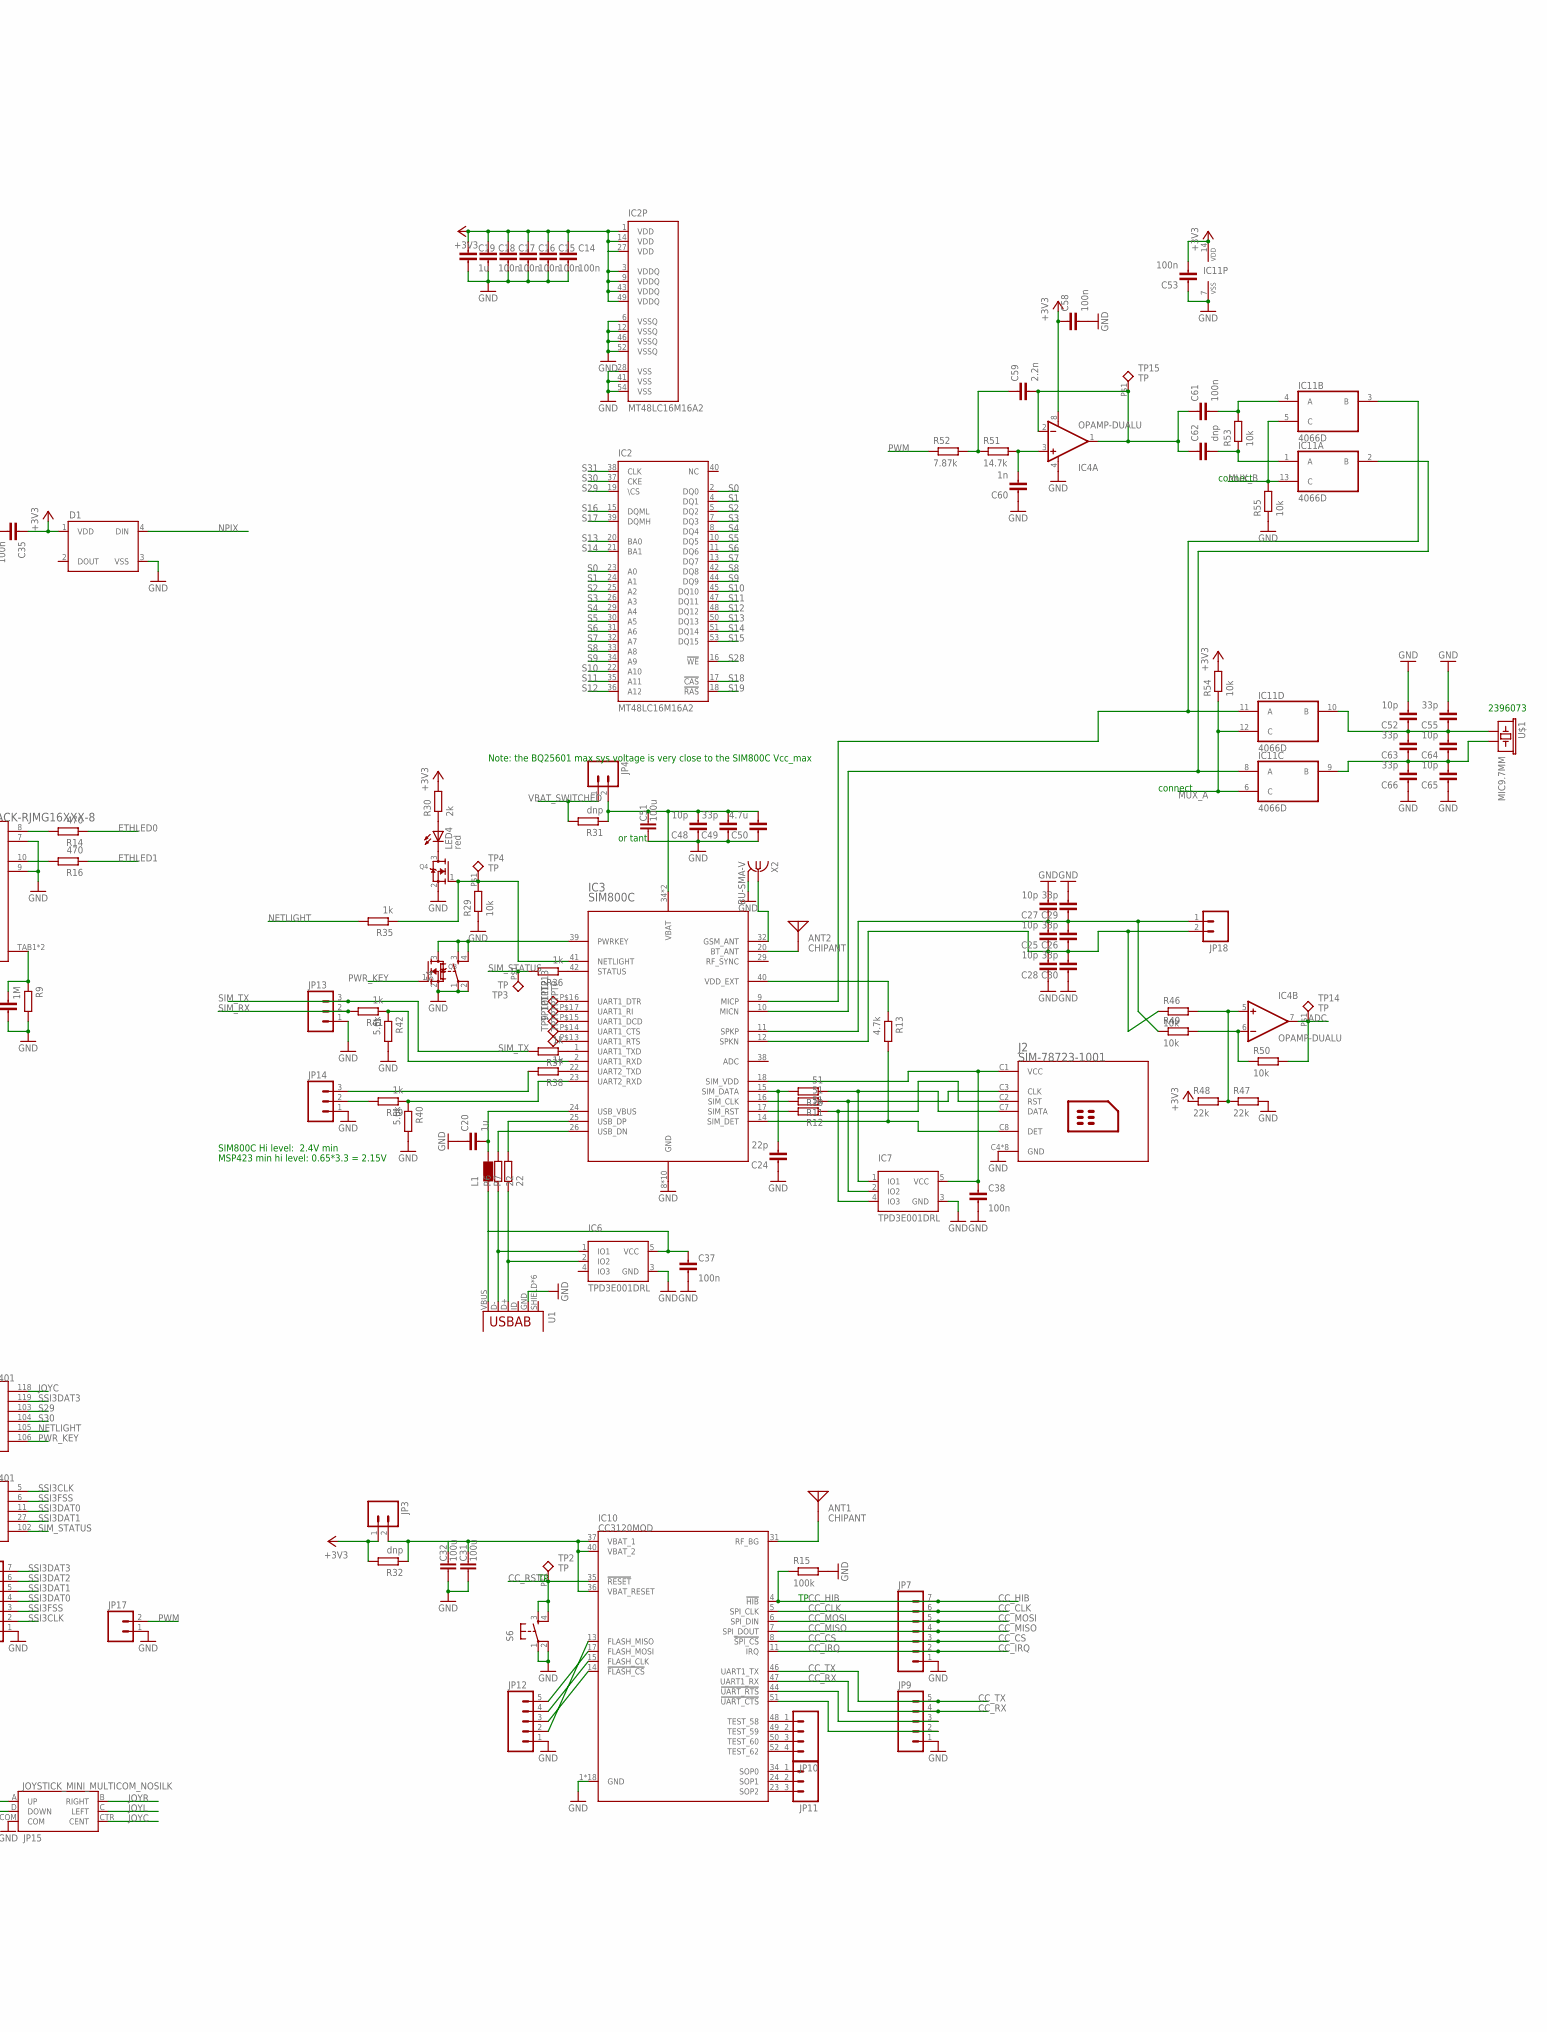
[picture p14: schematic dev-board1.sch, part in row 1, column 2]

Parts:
ANT1, ANT2: CHIPANT; 2450AT42A100; FARNELL 2148522
C1, C2, C3, C4, C5, C8, C9, C14, C15, C16, C17, C18, C21, C22, C33, C35, C36, C37, C38, C53, C58, C61: 100n; C0603-N
C6, C19, C20, C39: 1u; C0603-N
C7: 2.2u; C0603-N
C10, C11, C12, C13: 12p; C0603-N
C23, C60: 1n; C0603-N
C24: 22p; C0603-N
C25, C27, C28, C48, C52, C64, C65: 10p; C0603-N
C26, C29, C30, C49, C55, C63, C66: 33p; C0603-N
C31, C32, C51: 100u; C1210; FARNELL 1889302
C34, C43, C50: 4.7u; C0603-N; FARNELL 2524873
C40: 47n; C0603-N
C41, C42, C44: 10u; C0805-N; FARNELL 2112853/2362101/2576756
C45, C46, C47: 0805/10u/10V/X5R; C0805-N; FARNELL 2112853/2362101/2576756
C59: 2.2n; C0603-N
C62: dnp; C0603-N
D1: WS2812B
IC1: MSP432E401; QFP128-0.4
IC2: MT48LC16M16A2; TSOP54-400; FARNELL 2253738
IC3: SIM800C
IC4: OPAMP-DUALU; SO08; FARNELL 2463666
IC5, IC6, IC7: TPD3E001DRL; DRL-5
IC8: BQ25601; QFN-24
IC9: TPS62082; WSON8; FARNELL 2064227
IC10: CC3120MOD; CC3100MOD-LWK
IC11: 4066D; SO14; FARNELL 1201330
J1: MAGJACK-RJMG16XXX-8; RJMG163118101NR; FARNELL 1357436
J2: SIM-78723-1001; MSIM-MOLEX; FARNELL 2213306
J3: ER-TFT024-3; FH12-50S-0.5SH
J4: SWD_SHROUD; SWD_PTH_SHROUD; FARNELL 1865285
JP1: TC2030-SWDNL; TC2030-MCP-NL
JP2: M02-JST-2MM-SMT; JST-2-SMD; FARNELL 9492615
JP3, JP4, JP5, JP17, JP18: M02PTH; 1X02
JP6, JP7, JP16: M07; 1X07
JP8, JP10: M04PTH; 1X04
JP9, JP12: M05PTH; 1X05
JP11, JP13, JP14: M03PTH; 1X03
JP15: JOYSTICK_MINI_MULTICOM_NOSILK; JOYSTICK_MULTICOMP_NOSILK; FARNELL 1316987
L1, L2: WE-CBF_0805; WUERTH-0805; FARNELL 1781089
L3: 1.5u; 1008; FARNELL 2428202
L4: SRN2512-2R2M; 1008; FARNELL 2428203
LED1: green; LED-0603; FARNELL 2426215
LED2, LED3, LED4, LED5: red; LED-0603; FARNELL 2449874
Q2: MOSFET-N-SOT23-SPARK; SOT23-3; FARNELL 2724398
Q3, Q4: MOSFET-N-SOT23-SPARK; SOT23-3
Q6: CSD25402Q3A; Q3A; FARNELL 2501103
R1, R10, R11, R12: 51; R0603-N
R2, R9: 1M; R0603-N
R3: 4.87k; R0603-N; FARNELL 2447387
R4, R8, R27, R28, R29, R45, R46, R49, R50, R53, R54, R55: 10k; R0603-N
R5, R22, R23, R25, R30, R34: 2k; R0603-N
R6, R7: 22; R0603-N
R13, R26, R43, R44: 4.7k; R0603-N
R14, R16: 470; R0603-N
R15: 100k; R0603-N
R17, R18, R19, R20: 12; R0603-N
R21: 4k7; R0603-N
R24, R31, R32, R33: dnp; R0603-N
R35, R36, R37, R38, R39, R41: 1k; R0603-N
R40, R42: 5.6k; R0603-N
R47, R48: 22k; R0603-N
R51: 14.7k; R0603-N
R52: 7.87k; R0603-N
S1, S2, S3, S4, S6: 6MMTACTSMSM; 6MMTACTSM; FARNELL 2320087
S5: CUS-12TB; SWITCH-SPST-SMD-A; FARNELL 9575146
TP1, TP2, TP3, TP4, TP7, TP8, TP9, TP10, TP11, TP12, TP13, TP14, TP15: TP
U1, U2: USB-AB-LWK; USB-AB-MICRO-SMD_LWK; FARNELL 2293755
U$1: MIC9.7MM; MIC-9.7MM; FARNELL 2396073
X1: RESONATOR_EPSON_FC_145; FARNELL 2723239
X2: BU-SMA-V; FARNELL 1248990
Y1: CRYSTAL5X3; CRYSTAL-SMD-5X3; FARNELL 2508925

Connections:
+3V3: C1.1, C2.1, C3.1, C4.1, C14.1, C15.1, C16.1, C17.1, C18.1, C19.1, C21.2, C22.2, C33.2, C34.2, C35.1, C45.1, C47.1, C53.2, C58.1, D1.1 (VDD), IC1.7 (VDD), IC1.8 (VDDA), IC1.9 (REFA+), IC1.16 (VDD), IC1.26 (VDD), IC1.28 (VDD), IC1.39 (VDD), IC1.47 (VDD), IC1.51 (VDD), IC1.52 (VDD), IC1.69 (VDD), IC1.79 (VDD), IC1.90 (VDD), IC1.101 (VDD), IC1.113 (VDD), IC1.122 (VDD), IC2.1 (VDD), IC2.3 (VDDQ), IC2.9 (VDDQ), IC2.14 (VDD), IC2.27 (VDD), IC2.43 (VDDQ), IC2.49 (VDDQ), IC4.8 (V+), IC9.5 (VOS), IC11.14 (VDD), J1.1 (TCT), J1.6 (RCT), J3.1 (LEDA), J3.7 (IM1), J3.8 (IM2), J3.9 (IM3), J3.35 (RD), J3.40 (VDDI), J3.41 (VDDI), J3.42 (VCI), J4.1 (VCC), JP1.1 (VCC), JP3.1, L4.2, R1.2, R2.2, R4.2, R30.2, R32.2, R43.1, R44.1, R48.1, R54.2, TP8.P$1
ADC: IC1.128 (PD7), IC4.7 (OUT), R50.2, TP14.P$1
BQ_INT: IC1.124 (PE5), IC8.7 (!INT), JP8.2
BQ_SCL: IC1.121 (PB4), IC8.5 (SCL), JP8.4, R43.2
BQ_SDA: IC1.120 (PB5), IC8.6 (SDA), JP8.3, R44.2
CC_CLK: IC1.4 (PD3), IC10.5 (SPI_CLK), JP7.6
CC_CS: IC1.3 (PD2), IC10.8 (!SPI_CS), JP7.3
CC_HIB: IC1.14 (PE1), IC10.4 (!HIB), JP7.7, R15.1
CC_IRQ: IC1.15 (PE0), IC10.11 (IRQ), JP7.2
CC_MISO: IC1.1 (PD0), IC10.7 (SPI_DOUT), JP7.4
CC_MOSI: IC1.2 (PD1), IC10.6 (SPI_DIN), JP7.5
CC_RST: IC1.18 (PK0), IC10.35 (!RESET), S6.3, S6.4, TP2.P$1
CC_RX: IC1.126 (PD5), IC10.47 (UART1_RX), JP9.4
CC_TX: IC1.125 (PD4), IC10.46 (UART1_TX), JP9.5
ETHLED0: IC1.63 (PK4), R14.1
ETHLED1: IC1.61 (PK6), R16.1
ETHLED2: IC1.43 (PF1), R34.2
GGGG: IC3.2 (UART1_RXD), R41.1, R42.1
GND: C1.2, C2.2, C3.2, C4.2, C5.2, C6.2, C7.2, C8.2, C9.2, C10.2, C11.2, C12.2, C13.2, C14.2, C15.2, C16.2, C17.2, C18.2, C19.2, C20.1, C21.1, C22.1, C23.1, C24.1, C27.2, C28.1, C29.2, C30.1, C31.2, C32.2, C33.1, C34.1, C35.2, C36.2, C37.2, C38.2, C39.2, C41.2, C42.2, C43.2, C44.2, C45.2, C46.2, C47.2, C48.1, C49.1, C50.1, C51.2, C52.2, C53.1, C55.2, C58.2, C60.1, C65.1, C66.1, D1.3 (VSS), IC1.10 (GNDA), IC1.17 (GND), IC1.48 (GND), IC1.55 (GND), IC1.58 (GND), IC1.80 (GND), IC1.114 (GND), IC2.6 (VSSQ), IC2.12 (VSSQ), IC2.28 (VSS), IC2.41 (VSS), IC2.46 (VSSQ), IC2.52 (VSSQ), IC2.54 (VSS), IC3.8 (GND), IC3.13 (GND), IC3.19 (GND), IC3.21 (GND), IC3.27 (GND), IC3.30 (GND), IC3.31 (GND), IC3.33 (GND), IC3.36 (GND), IC3.37 (GND), IC4.4 (V-), IC5.3 (GND), IC6.3 (GND), IC7.3 (GND), IC8.17 (GND), IC8.18 (GND), IC8.25 (GND), IC9.2 (GND), IC9.3 (MODE), IC9.EP (GND), IC10.1 (GND), IC10.2 (GND), IC10.16 (GND), IC10.27 (GND), IC10.28 (GND), IC10.30 (GND), IC10.32 (GND), IC10.38 (GND), IC10.43 (GND), IC10.55 (GND), IC10.56 (GND), IC10.57 (GND), IC10.58 (GND), IC10.59 (GND), IC10.60 (GND), IC10.61 (GND), IC10.62 (GND), IC10.63 (GND), IC11.7 (VSS), J1.7 (LED1-), J1.9 (LED2-), J2.C4 (GND), J2.C5 (GND), J2.GND1 (GND), J2.GND2 (GND), J2.GND3 (GND), J2.GND4 (GND), J2.GND5 (GND), J2.GND6 (GND), J3.6 (IM0), J3.11 (VSYNC), J3.12 (HSYNC), J3.13 (DOTCLK), J3.14 (DE), J3.15 (DB17), J3.16 (DB16), J3.17 (DB15), J3.18 (DB14), J3.19 (DB13), J3.20 (DB12), J3.21 (DB11), J3.22 (DB10), J3.23 (DB9), J3.24 (DB8), J3.25 (DB7), J3.26 (DB6), J3.27 (DB5), J3.28 (DB4), J3.29 (DB3), J3.30 (DB2), J3.31 (DB1), J3.32 (DB0), J3.43 (GND), J3.48 (GND), J3.49 (GND), J3.50 (GND), J4.3 (GND1), J4.5 (GND2), J4.9 (GNDD), JP1.5 (GND), JP2.1, JP6.1, JP7.1, JP8.1, JP9.1, JP12.1, JP13.1, JP14.1, JP15.COM, JP16.1, JP17.1, LED1.C, LED2.C, LED5.C, Q2.2 (S), Q3.2 (S), Q4.2 (S), R3.1, R9.2, R15.2, R23.2, R24.2, R28.2, R29.1, R40.2, R42.2, R47.2, R55.1, S1.1, S1.2, S2.1, S2.2, S3.1, S3.2, S4.1, S4.2, S5.2, S6.1, S6.2, U1.GND, U2.GND, X2.2, X2.3 (2), X2.4 (2), X2.5 (2)
JOYC: IC1.118 (PP0), JP15.CTR (CENT)
JOYD: IC1.107 (PN0), JP15.D (DOWN)
JOYL: IC1.73 (PM5), JP15.C (LEFT)
JOYR: IC1.74 (PM4), JP15.B (RIGHT)
JOYU: IC1.71 (PM7), JP15.A (UP)
LCD_BLIGHT: IC1.42 (PF0), Q2.1 (G)
LCD_CLK: IC1.35 (PA2), J3.37 (D/CX(SCL)), JP6.7
LCD_CS: IC1.36 (PA3), J3.38 (CSX), JP6.6
LCD_DCX: IC1.20 (PK2), J3.36 (WRX(D/CX)), JP6.2
LCD_MISO: IC1.38 (PA5), J3.33 (SDO), JP6.4
LCD_MOSI: IC1.37 (PA4), J3.34 (SDI), JP6.5
LCD_RST: IC1.21 (PK3), J3.10 (RESET)
LCD_TEAR: IC1.19 (PK1), J3.39 (TE), JP6.3
LEDA: IC1.95 (PB0), R21.2
LEDB: IC1.96 (PB1), R22.2
MUX_A: IC1.108 (PN1), IC11.6 (C), IC11.12 (C), R54.1
MUX_B: IC1.109 (PN2), IC11.5 (C), IC11.13 (C), R55.2
unnamed: IC1.89 (OSC1), R5.2
unnamed: C5.1, C6.1, C7.1, IC1.87 (VDDC), IC1.115 (VDDC)
unnamed: C42.1, IC8.13 (BAT), IC8.14 (BAT), JP2.2
unnamed: C12.1, R5.1, Y1.1
unnamed: C13.1, IC1.88 (OSC0), Y1.3 (2)
unnamed: C10.1, IC1.66 (XOSC0), X1.P$1 (1)
unnamed: C8.1, IC1.68 (VBAT), R1.1
unnamed: C11.1, IC1.67 (XOSC1), X1.P$2 (2)
unnamed: IC1.64 (/WAKE), R2.1, S1.3, S1.4
unnamed: IC6.1 (IO1), R6.1, U1.D-
unnamed: IC1.59 (RBIAS), R3.2
unnamed: IC3.32 (GSM_ANT), X2.1
unnamed: IC6.2 (IO2), R7.1, U1.D+
unnamed: IC3.25 (USB_DP), R7.2
unnamed: IC3.26 (USB_DN), R6.2
unnamed: IC5.4 (IO3), R8.2, U2.ID (USBID)
unnamed: C36.1, IC5.5 (VCC), L2.2, U2.VBUS
unnamed: C20.2, IC3.24 (USB_VBUS), L1.2
unnamed: C37.1, IC6.5 (VCC), L1.1, U1.VBUS
unnamed: IC1.53 (EN0RXIN), J1.5 (RX-)
unnamed: IC1.54 (EN0RXIP), J1.4 (RX+)
unnamed: IC1.56 (EN0TXON), J1.3 (TX-)
unnamed: IC1.57 (EN0TXOP), J1.2 (TX+)
unnamed: C23.2, J1.TAB1 (SHIELD), J1.TAB2 (SHIELD), R9.1
unnamed: J1.8 (LED1+), R14.2
unnamed: J1.10 (LED2+), R16.2
unnamed: C24.2, IC3.15 (SIM_DATA), R10.2
unnamed: IC3.16 (SIM_CLK), R11.2
unnamed: IC3.17 (SIM_RST), R12.2
unnamed: IC7.1 (IO1), J2.C7 (DATA), R10.1
unnamed: IC7.2 (IO2), J2.C3 (CLK), R11.1
unnamed: IC7.4 (IO3), J2.C2 (RST), R12.1
unnamed: IC3.14 (SIM_DET), J2.C8 (DET), R13.2
unnamed: IC3.40 (VDD_EXT), R13.1
unnamed: C38.1, IC3.18 (SIM_VDD), IC7.5 (VCC), J2.C1 (VCC)
unnamed: IC4.5 (+IN), R46.2, R47.1, R48.2
unnamed: IC3.9 (MICP), IC11.3 (B), IC11.11 (A)
unnamed: LED5.A, R34.1
unnamed: C25.2, C26.2, C27.1, C29.1, IC3.11 (SPKP), JP18.1, R49.1
unnamed: C25.1, C26.1, C28.2, C30.2, IC3.12 (SPKN), JP18.2, R46.1
unnamed: IC3.10 (MICN), IC11.2 (B), IC11.8 (A)
unnamed: IC10.48 (TEST_58), JP10.1
unnamed: IC10.44 (!UART_RTS), JP9.3
unnamed: C48.2, C49.2, C50.2, C51.1, IC3.34 (VBAT), IC3.35 (VBAT), JP4.2, R31.1
unnamed: LED4.C, Q4.3 (D)
unnamed: ANT1.P$1, IC10.31 (RF_BG)
unnamed: IC10.51 (!UART_CTS), JP9.2
unnamed: C31.1, C32.1, IC10.36 (VBAT_RESET), IC10.37 (VBAT_1), IC10.40 (VBAT_2), JP3.2, R32.1
unnamed: IC10.49 (TEST_59), JP10.2
unnamed: IC10.50 (TEST_60), JP10.3
unnamed: IC3.39 (PWRKEY), Q3.3 (D), S4.3, S4.4
unnamed: IC10.52 (TEST_62), JP10.4
unnamed: IC10.34 (SOP0), JP11.1
unnamed: J3.2 (LEDK1), R17.1
unnamed: J3.3 (LEDK2), R18.1
unnamed: J3.4 (LEDK3), R19.1
unnamed: J3.5 (LEDK4), R20.1
unnamed: Q2.3 (D), R17.2, R18.2, R19.2, R20.2
unnamed: IC10.24 (SOP1), JP11.2
unnamed: ANT2.P$1, IC3.20 (BT_ANT)
unnamed: C40.1, IC8.19 (SW), IC8.20 (SW), L3.1
unnamed: LED4.A, R30.1
unnamed: IC10.23 (SOP2), JP11.3
unnamed: IC10.15 (FLASH_CLK), JP12.4
unnamed: LED1.A, R21.1
unnamed: LED2.A, R22.1
unnamed: IC10.14 (!FLASH_CS), JP12.3
unnamed: IC10.17 (FLASH_MOSI), JP12.5
unnamed: IC10.13 (FLASH_MISO), JP12.2
unnamed: IC3.22 (UART2_TXD), R38.1
unnamed: C40.2, IC8.21 (BTST)
unnamed: C43.1, IC8.22 (REGN), R27.1
unnamed: C44.1, IC8.23 (PMID)
unnamed: IC8.12 (!QON), S3.3, S3.4
unnamed: JP14.3, R38.2
unnamed: IC8.9 (!CE), R23.1
unnamed: IC8.2 (PSEL), R24.1, R25.2, TP1.P$1
unnamed: IC1.65 (/HIB), TP7.P$1
unnamed: C63.1, C64.1, C65.2, C66.2, IC11.9 (B), U$1.2
unnamed: IC3.42 (STATUS), R36.1
unnamed: IC8.4 (STAT), R26.2
unnamed: LED3.C, R26.1
unnamed: IC8.11 (TS), R27.2, R28.1
unnamed: IC4.6 (-IN), R49.2, R50.1
unnamed: C59.2, C61.1, C62.1, IC4.1 (OUT), IC4.2 (-IN), TP15.P$1
unnamed: IC3.1 (UART1_TXD), R37.1
unnamed: IC3.23 (UART2_RXD), R39.1, R40.1
unnamed: JP14.2, R39.2
unnamed: IC3.3 (UART1_RTS), TP9.P$1
unnamed: IC3.4 (UART1_CTS), TP10.P$1
unnamed: IC3.5 (UART1_DCD), TP11.P$1
unnamed: IC3.7 (UART1_RI), TP12.P$1
unnamed: IC3.6 (UART1_DTR), TP13.P$1
unnamed: C60.2, IC4.3 (+IN), R51.2
unnamed: C59.1, R51.1, R52.2
unnamed: C61.2, IC11.4 (A), R53.2
unnamed: C62.2, IC11.1 (A), R53.1
unnamed: C52.1, C55.1, C63.2, C64.2, IC11.10 (B), U$1.1
NETLIGHT: IC1.105 (PP4), R35.2
NETLIGHT_: IC3.41 (NETLIGHT), Q4.1 (G), R29.2, R35.1, TP4.P$1
NPIX: D1.4 (DIN), IC1.123 (PE4)
NRST: C9.1, IC1.70 (/RST), J4.10 (NRST), JP1.3 (RST), R4.1, S2.3, S2.4
PWM: IC1.45 (PF3), JP17.2, R52.1
PWR_KEY: IC1.106 (PP5), Q3.1 (G)
S0: IC1.29 (PH0), IC2.2 (DQ0), IC2.23 (A0)
S1: IC1.30 (PH1), IC2.4 (DQ1), IC2.24 (A1)
S2: IC1.31 (PH2), IC2.5 (DQ2), IC2.25 (A2)
S3: IC1.32 (PH3), IC2.7 (DQ3), IC2.26 (A3)
S4: IC1.22 (PC7), IC2.8 (DQ4), IC2.29 (A4)
S5: IC1.23 (PC6), IC2.10 (DQ5), IC2.30 (A5)
S6: IC1.24 (PC5), IC2.11 (DQ6), IC2.31 (A6)
S7: IC1.25 (PC4), IC2.13 (DQ7), IC2.32 (A7)
S8: IC1.40 (PA6), IC2.33 (A8), IC2.42 (DQ8)
S9: IC1.41 (PA7), IC2.34 (A9), IC2.44 (DQ9)
S10: IC1.50 (PG1), IC2.22 (A10), IC2.45 (DQ10)
S11: IC1.49 (PG0), IC2.35 (A11), IC2.47 (DQ11)
S12: IC1.75 (PM3), IC2.36 (A12), IC2.48 (DQ12)
S13: IC1.76 (PM2), IC2.20 (BA0), IC2.50 (DQ13)
S14: IC1.77 (PM1), IC2.21 (BA1), IC2.51 (DQ14)
S15: IC1.78 (PM0), IC2.53 (DQ15)
S16: IC1.81 (PL0), IC2.15 (DQML)
S17: IC1.82 (PL1), IC2.39 (DQMH)
S18: IC1.83 (PL2), IC2.17 (!CAS)
S19: IC1.84 (PL3), IC2.18 (!RAS)
S28: IC1.92 (PB3), IC2.16 (!WE)
S29: IC1.103 (PP2), IC2.19 (\CS)
S30: IC1.104 (PP3), IC2.37 (CKE)
S31: IC1.62 (PK5), IC2.38 (CLK)
SIM_RX: IC1.117 (PJ1), JP13.2, R41.2
SIM_STATUS: IC1.102 (PQ4), R36.2, TP3.P$1
SIM_TX: IC1.116 (PJ0), JP13.3, R37.2
SSI3CLK: IC1.5 (PQ0), JP16.2
SSI3DAT0: IC1.11 (PQ2), JP16.4
SSI3DAT1: IC1.27 (PQ3), JP16.5
SSI3DAT2: IC1.46 (PF4), JP16.6
SSI3DAT3: IC1.119 (PP1), JP16.7
SSI3FSS: IC1.6 (PQ1), JP16.3
SW: IC9.7 (SW), L4.1
SWCLK: IC1.100 (PC0), J4.4 (SWCLK), JP1.4 (SWCLK)
SWDAT: IC1.99 (PC1), J4.2 (SWDAT), JP1.2 (SWDAT)
SWO: IC1.97 (PC3), J4.6 (SWO), JP1.6 (SWO)
USB_ID: IC1.85 (PL4), R8.1
USB_N: IC1.93 (PL7), IC5.1 (IO1), U2.D-
USB_P: IC1.94 (PL6), IC5.2 (IO2), U2.D+
USB_VBUS: C39.1, IC1.86 (PL5), IC8.1 (VAC), IC8.24 (VBUS), L2.1, LED3.A
VBAT_SWITCHED: C46.1, IC9.1 (EN), IC9.8 (VIN), JP4.1, Q6.1 (D), Q6.2 (D), Q6.3 (D), R31.2
VBAT_SWITCH_CONTROL: Q6.4 (G), R45.1, S5.3 (S)
VBAT_UNSWITCH: JP5.2, Q6.5 (S), Q6.6 (S), Q6.7 (S), Q6.8 (S), Q6.EP (S), R33.1, R45.2
V_UNREG: C41.1, IC8.15 (SYS), IC8.16 (SYS), JP5.1, L3.2, R25.1, R33.2

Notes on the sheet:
timer
1: serial
3V3 Regulator
10V
6mA max
POWER SWITCH
Battery Switch
CHECK ALL SPI PINS (TI names are different to mosi etc)
or tant
2396073
2724398
SIM800C Hi level: 2.4V min
MSP423 min hi level: 0.65*3.3 = 2.15V
Note: the BQ25601 max sys voltage is very close to the SIM800C Vcc_max
pwm
connect

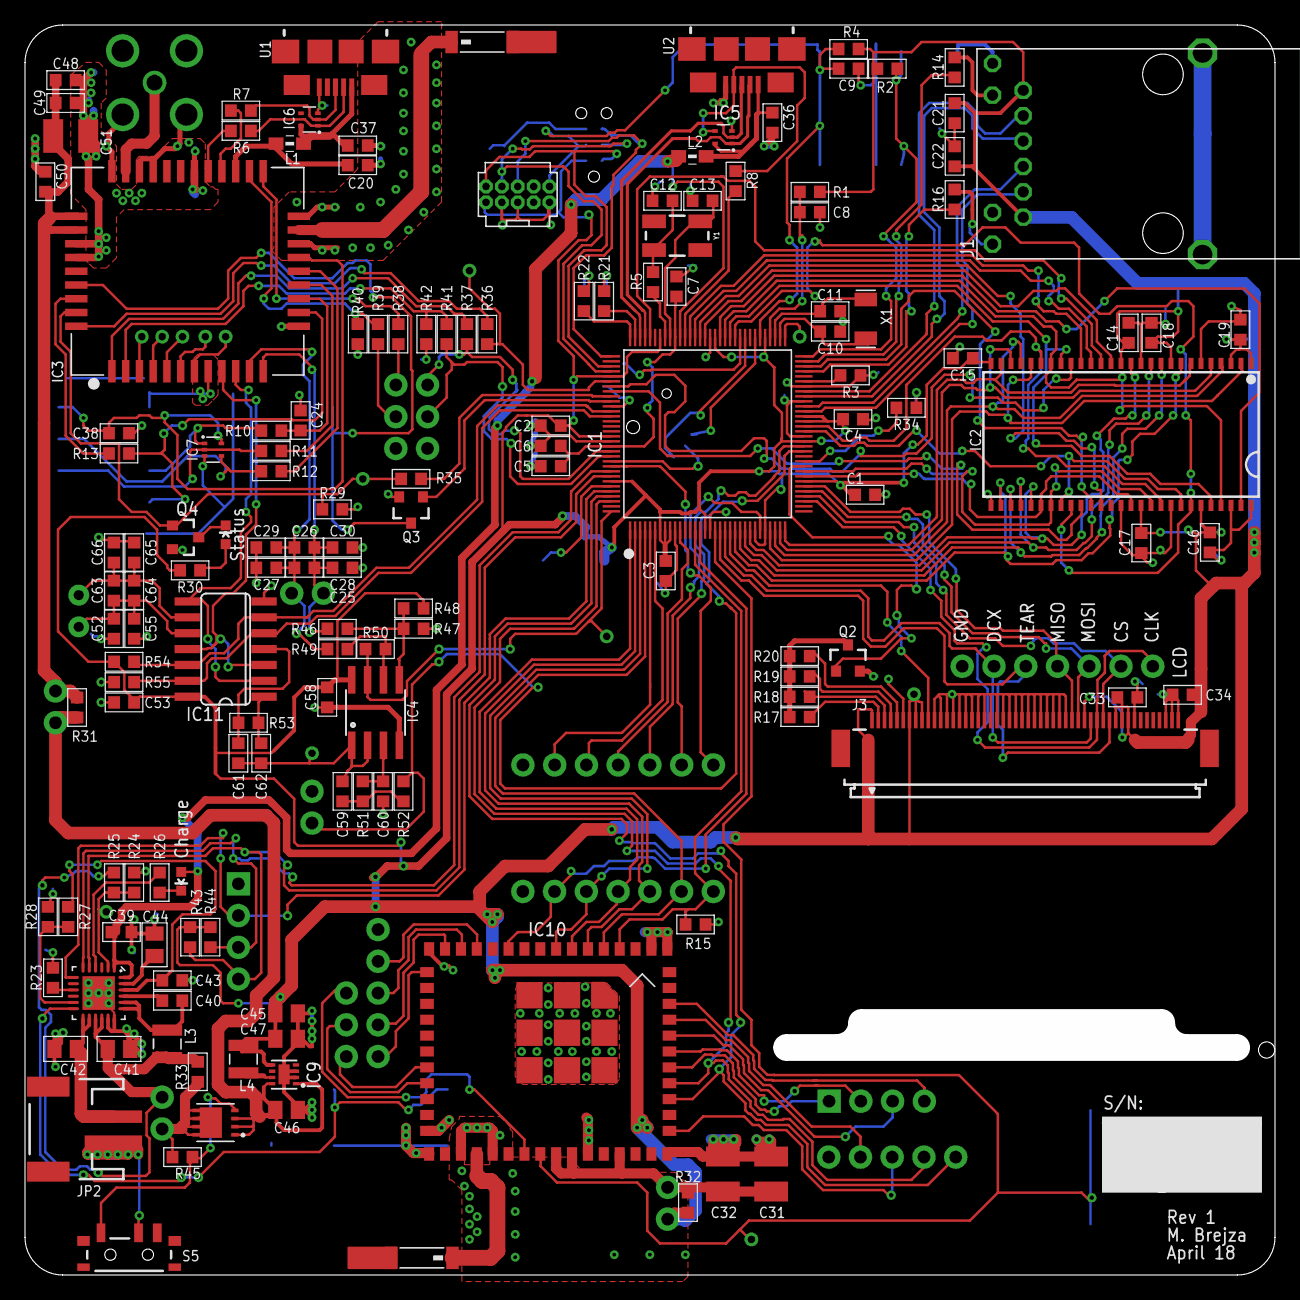
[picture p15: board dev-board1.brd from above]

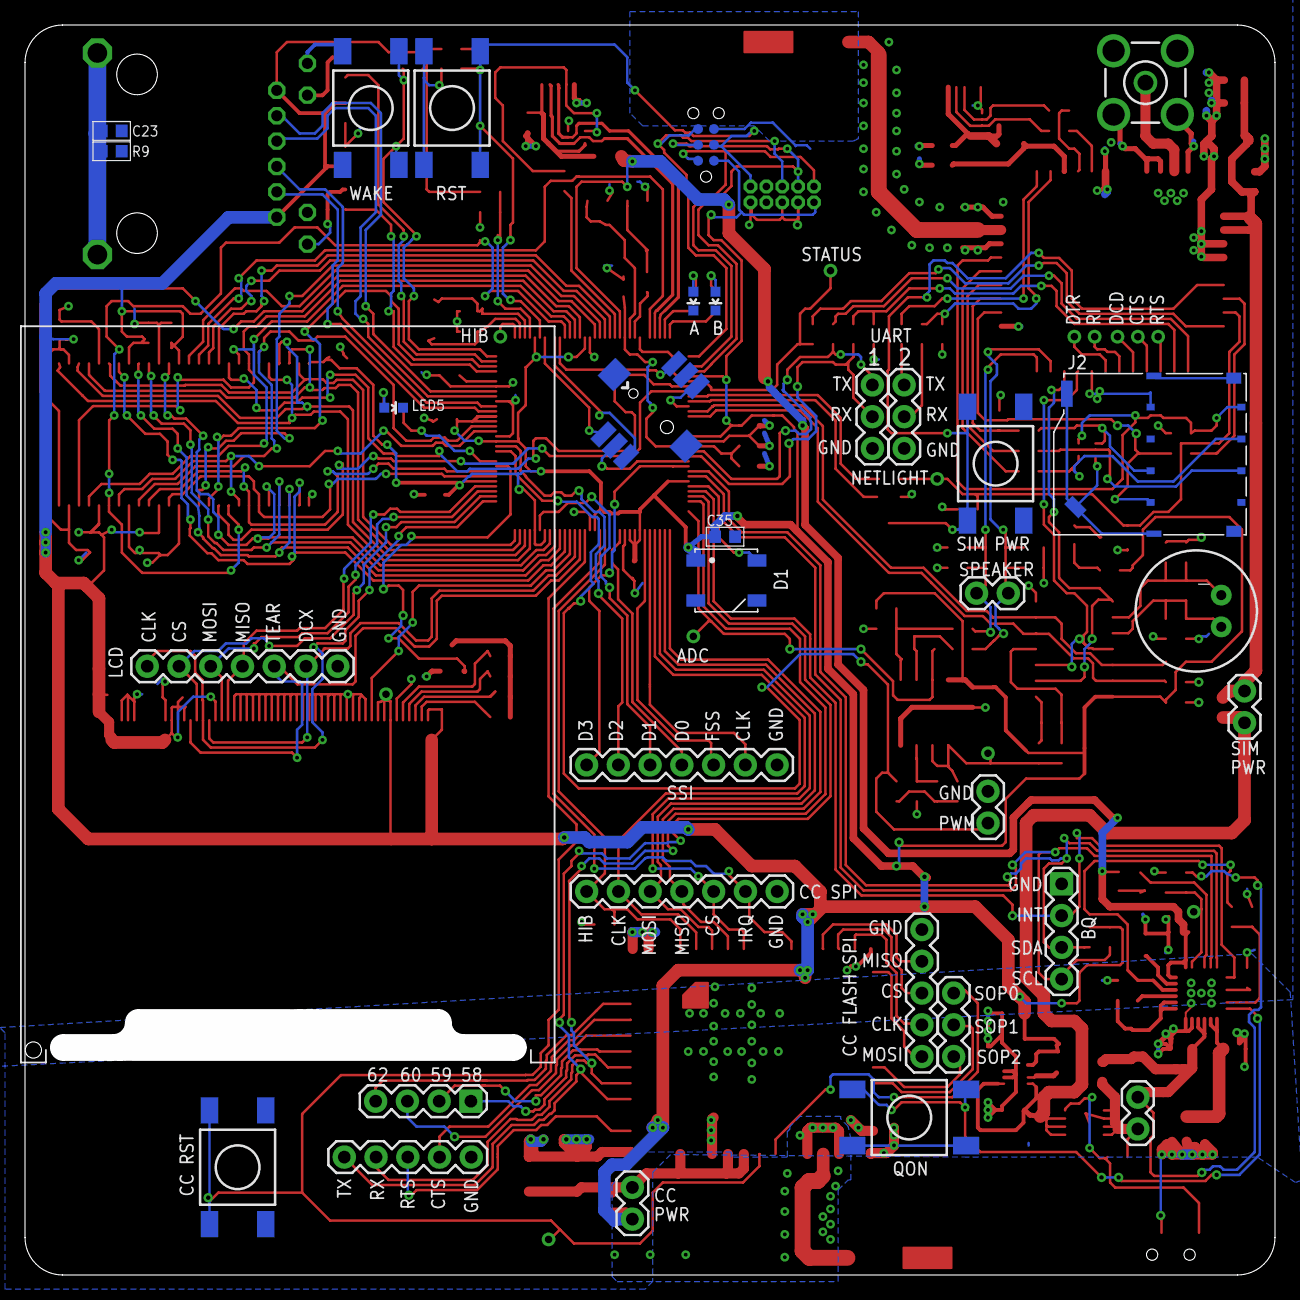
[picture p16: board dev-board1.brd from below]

Board: 2 copper layers, 100.0 x 100.0 mm, 193 parts (36 on the bottom side), 185 nets.

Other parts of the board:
U3: ER-TFT024-3-OUTLINE; ER-TFT024-3

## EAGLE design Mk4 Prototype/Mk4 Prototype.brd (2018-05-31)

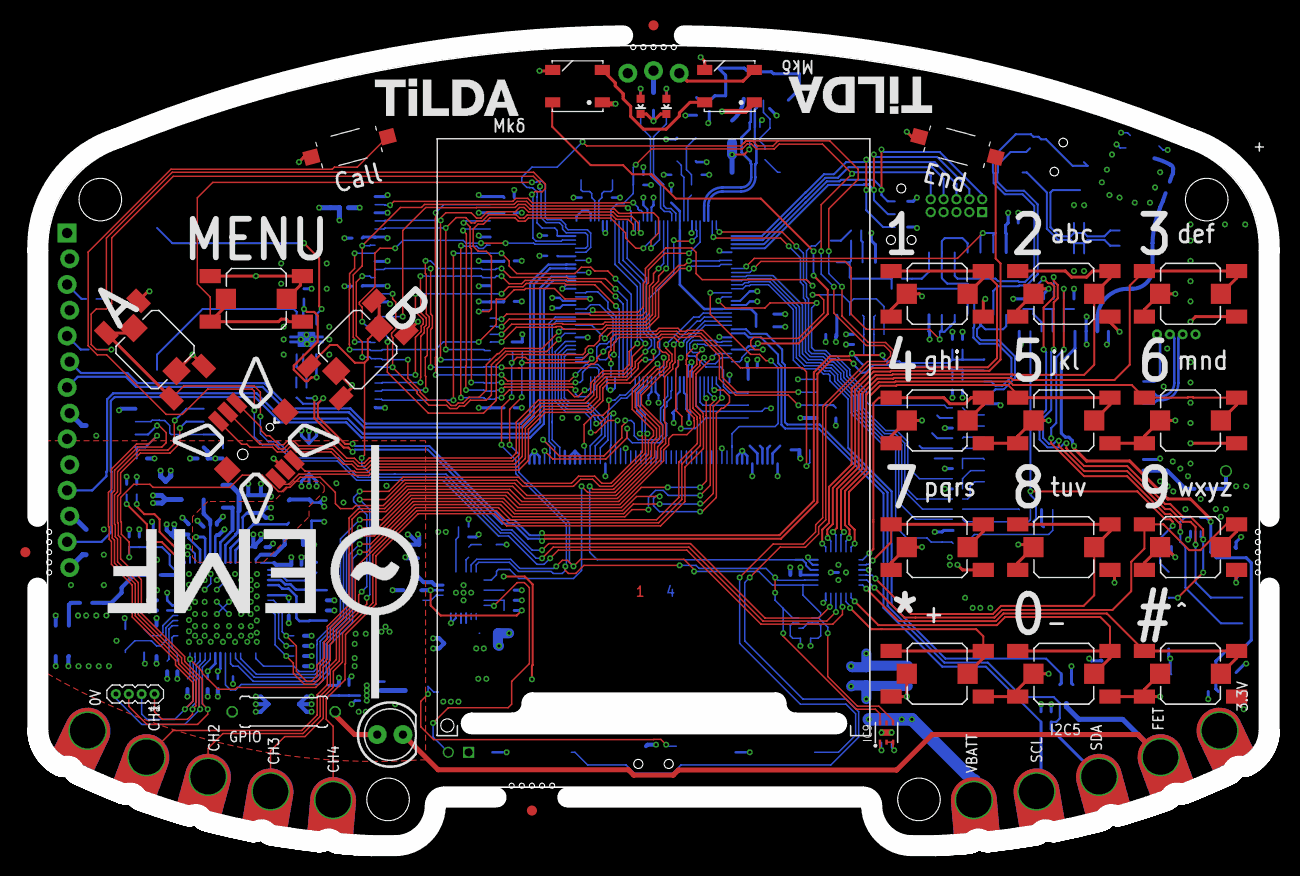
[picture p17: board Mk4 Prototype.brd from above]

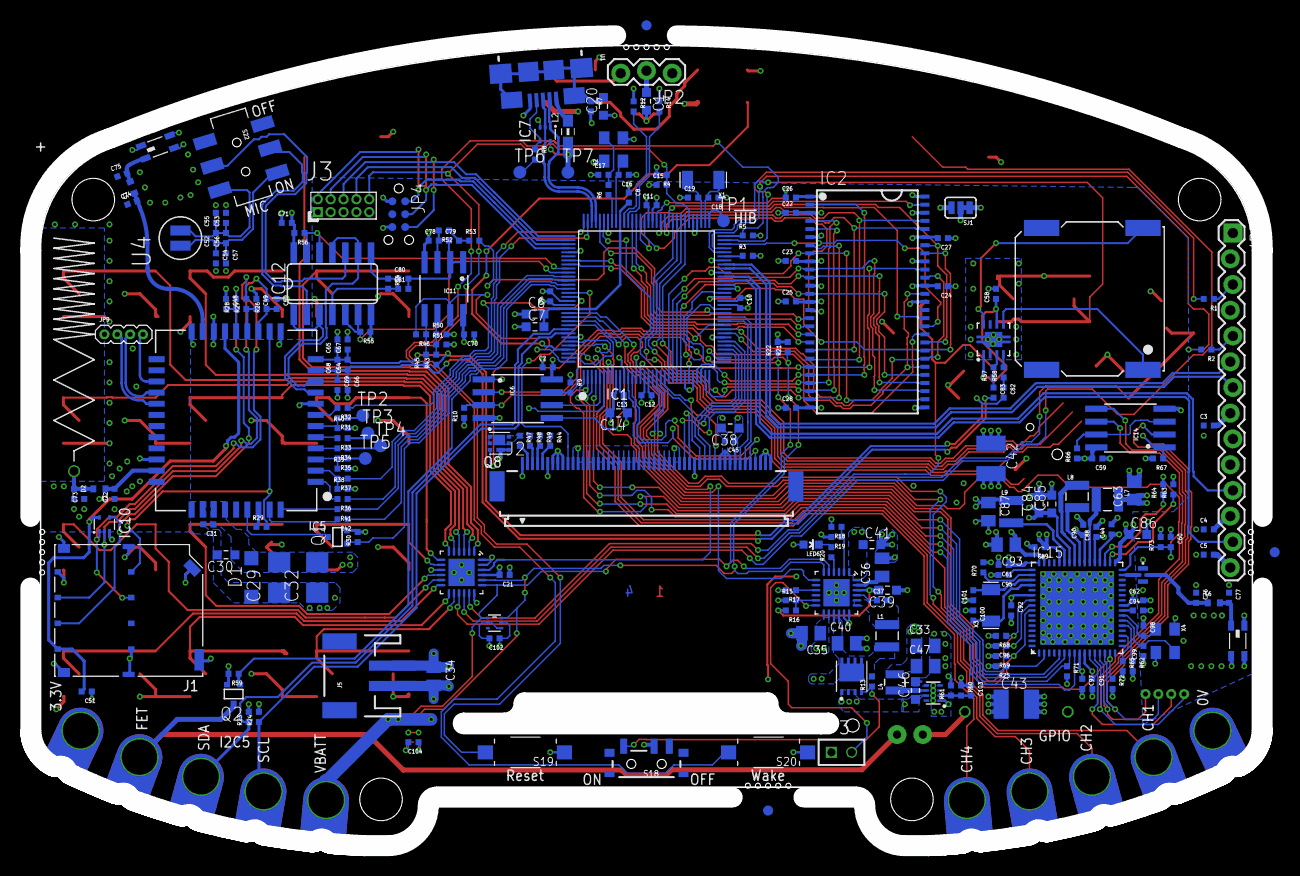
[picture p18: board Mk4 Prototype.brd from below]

Board: 4 copper layers, 121.6 x 80.0 mm, 278 parts (242 on the bottom side), 234 nets.

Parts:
ANT1, ANT2: 2450AT18D0100
ARTWORK1: ARTWORK_JOYSTICK; TILDA_ARTWORK_JOYSTICK
ARTWORK2: ARTWORK_KEYPAD; TILDA_ARTWORK_KEYPAD
BATT: 1000mAh JST-PH; BATTERY-32X50
C1, C7, C14, C41, C86: 0603/1u/6V3/X5R; C0603K-SMALL
C2, C3, C4, C5, C8, C9, C10, C11, C12, C13, C15, C21, C22, C23, C24, C25, C26, C27, C28, C31, C44, C45, C51, C58, C59, C60, C61, C62, C70, C71, C80, C81, C91, C92, C94, C95, C96, C97, C102, C104: 0402/100n/10V/X5R; C0402-SMALLER
C6: 0603/2u2/6V3/X5R; C0603K-SMALL
C16, C17, C18, C19, C98, C99, C100, C101: 0402/12p/50V/C0G; C0402-SMALLER
C20: 0603/3n3/50V/X7R; C0603K-SMALL
C29, C32: 1411/100u/10V/Tant; CT3528
C30, C38, C39, C46: 0603/4u7/10V/X5R; C0603K-SMALL
C33, C34, C35, C36, C40, C47, C63, C87, C93: 0805/10u/10V/X5R; C0805-N
C37: 0402/47n/10V/X5R; C0402-SMALLER
C42, C43: 1210/100u/6V3/X5R; C1210K
C48, C49, C50: 0402/22p/10V/C0G; C0402-SMALLER
C52, C54, C55, C64, C66, C67: 0402/33p/50V/C0G; C0402-SMALLER
C53, C56, C57, C65, C68, C69: 0402/10p/50V/C0G; C0402-SMALLER
C72, C73, C74, C75, C76, C77: C0402-SMALLER
C78: 0402/1n/10V/X5R; C0402-SMALLER
C79: 0402/2n2/10V/X5R; C0402-SMALLER
C82, C83: 0402/220n/6V/X5R; C0402-SMALLER
C84, C85: 0603/22u/4V/X5R; C0603K-SMALL
C88, C89, C90: 0402/4u7/6V3/X5R; C0402-SMALLER
C103: 0402/120p/50V/C0G; C0402-SMALLER
D1: MMSZ5231BT1G; SOD123
D2: LXES15AAA1-153; R0402-SMALLER
FID1, FID2, FID3, FID4, FID5, FID6: FIDUCIAL1X2.5-STOP; FIDUCIAL-1X2.5-STOP
FL1: DEA202450BT-1294C1-H; DEA202450BT
IC1: MSP432E401; QFP128-0.4
IC2: AS4C4M16SA-7TCN; TSOP54-400
IC3: TPS62822DLCR; VSON-HR
IC4: TCA9555RGER; QFN-24
IC5: SIM800C
IC6: SST26VF016B-104I/SM; SO08-EIAJ
IC7, IC10: TPD3E001DRL; DRL-5
IC8: BQ25601; QFN-24
IC9: OPT3001; USON-6
IC11: LMV358ID; SO08
IC12: SN74HC4066D; SO14
IC13: TPA2006D1; VSON-8
IC14: MX25R1635FM1IL0; SO08-EIAJ
IC15: CC3120R; VQFN-64
J1: 78723-1001; MSIM-MOLEX-LWK
J2: ER-CON50HT-1; FH12-50S-0.5SH
J3: 2x5 1.27mm; PINHEAD_2X05_127
J4: GSM-COIL-ANT; GSM-ANTENNA
J5: S2B-PH-SM4-TB(LF)(SN); JST-2-SMD
JP2: 1x03; 1X03_LOCK
JP3: 1x02 2MM; 1X02_2MM
JP4: TC2030-MCP-NL
JP7: 1x14; 1X14_LOCK
JP8, JP9: 1x04_1.27MM; 1X04-1.27MM
L1: SRN2512-2R2M; 1008
L2: BLM18KG121TN1D; WUERTH-0805
L3, L5, L6: 0402/0R/5%; L0402
L4: DFE201610E-R47M=P2; 0806
L7, L9: LQM2HPN2R2MG0L; 1008
L8: LQM2HPN1R0MG0L; 1008
LAYERS1: LAYER_NUMBRS_4_SMALL; LAYER_NUMBERS_4_SMALL
LCD: ER-TFT024-3
LED1, LED2: WS2812B
LED3, LED6: 0603 RED; LED-0603-CORRECT
LED4: 0603 GREEN; LED-0603-CORRECT
LED5: LED 5MM; LED5MM
LOGO1: EMFLOGO-BOTH; EMFLOGO
PCB: TiLDA Mk4 PCB; TILDA_MK4_OUTLINE
Q1, Q2: 2N7002PW; SC70-3-R
Q3: CSD25402Q3A; Q3A
Q8: CSD13202Q2; Q2
R1, R2, R31, R32, R33, R34, R35, R36, R37, R41, R42: 0402/1K/5%; R0402-SMALLER
R3: 0402/4K87/5%; R0402-SMALLER
R4, R9, R10, R13, R15, R16, R18, R19, R20, R43, R45, R46, R54, R55, R56, R59, R62, R66: 0402/10K/5%; R0402-SMALLER
R5, R7: 0402/1M/5%; R0402-SMALLER
R6, R12, R17: 0402/2K/5%; R0402-SMALLER
R8: 0402/100R/5%; R0402-SMALLER
R11: 0309/10
R14, R21, R22, R23, R24, R29: 0402/4K7/5%; R0402-SMALLER
R25, R30, R63, R64, R65, R67, R68, R69, R70, R71, R72, R73: 0402/100K/5%; R0402-SMALLER
R26, R27, R28: 0402/51R/5%; R0402-SMALLER
R38, R39, R40: 0402/5K6/5%; R0402-SMALLER
R44, R47, R48, R49: 0402/12R/5%; R0402-SMALLER
R50, R51: 0402/22K/5%; R0402-SMALLER
R52: 0402/14K7/5%; R0402-SMALLER
R53: 0402/7K87/5%; R0402-SMALLER
R57, R58: 0402/150K/1%; R0402-SMALLER
R60: 0402/732K/5%; R0402-SMALLER
R61: 0402/162K/5%; R0402-SMALLER
S1, S2, S3, S4, S5, S6, S7, S8, S9, S10, S11, S12, S13, S14, S15: SKPMAPE010; SKPMAPE010-COMBINED
S16, S17, S19, S20: 3X6X2.5; TACTILE_SWITCH_SMD_3X6X2.5H
S18: CUS-12TB; SWITCH-SPST-SMD-A
S22: AYZ0202AGRLC; AYZ-JS-COMBINED
SJ1: Amp Power Select; SJ_3
SW1: JOYSTICK; JOYSTICK_MULTICOMP_NOSILK
TP1, TP2, TP3, TP4, TP5, TP6, TP7: TP; B1,27
U1: ZX62-B-5PA(33); USB-AB-MICRO-SMD_LWK
U2: TMP102; SOT563
U4: MIC-4MM; MIC-SMD-4MM
U5: LDMS1540S-01-R8-0.8-R; SPEAKER-15MM-SMD
X1, X3: ABS07-32.768KHZ-T; RESONATOR_EPSON_FC_145
X2: ABM8G-25.000MHZ-B4Y-T; CRYSTAL-3.2-2.5
X4: ABM8-40.000MHZ-10-1-U-T; CRYSTAL-3.2-2.5

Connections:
3V3: C2.2, C3.2, C4.2, C9.2, C10.2, C11.2, C12.2, C13.2, C14.2, C21.2, C22.2, C23.2, C24.2, C25.2, C26.2, C27.2, C28.2, C33.1, C38.2, C42.2, C43.2, C45.2, C47.1, C59.2, C70.2, C71.2, C88.1, C89.1, C90.1, C91.1, C92.1, C93.1, C102.1, C103.1, C104.1, IC1.7, IC1.8, IC1.9, IC1.16, IC1.26, IC1.28, IC1.39, IC1.47, IC1.51, IC1.52, IC1.68, IC1.69, IC1.79, IC1.90, IC1.101, IC1.113, IC1.122, IC2.1, IC2.3, IC2.9, IC2.14, IC2.27, IC2.43, IC2.49, IC4.21, IC6.8, IC9.1, IC11.8, IC12.14, IC14.8, IC15.10, IC15.37, IC15.39, IC15.44, IC15.47, IC15.54, J2.1, J2.7, J2.8, J2.9, J2.35, J2.40, J2.41, J2.42, J3.1, JP4.1, JP7.8, JP7.12, L4.2, PCB.3V3, R4.2, R5.2, R9.1, R10.1, R11.2, R21.2, R22.2, R23.2, R24.2, R50.2, R56.2, R60.1, R66.1, R67.2, R68.2, R69.2, R73.2, SJ1.1, SW1.COM, U2.5
3V3_POE: C5.2, JP7.14
!HIB: IC1.65, TP1.TP
!RESET: C15.2, IC1.70, J3.10, R4.1, S19.2
!WAKE: IC1.64, R5.1, S20.2
AIN0_ADC_X: IC1.13, J2.46
AIN1_ADC_Y: IC1.12, J2.47
AIN4_SPK_ADC: IC1.128, IC11.7, R46.2
AIN5_CH3: IC1.127, PCB.CH2
AMP_IN_N: IC13.4, R58.2
AMP_IN_P: IC13.3, R57.2
AMP_IN_R_N: C82.1, R58.1
AMP_IN_R_P: C83.1, R57.1
AMP_VDD: C58.1, IC13.1, IC13.6, SJ1.2
BQ_!CE: IC8.9, R17.1
BQ_!INT: IC1.14, IC8.7
BQ_!QON: IC8.12, JP3.2
BQ_PMID: C36.1, IC8.23
BQ_PSEL: IC8.2, R18.1, R19.1
BQ_REGN: C39.2, IC8.22, R16.2
BQ_STAT: IC8.4, R20.1
BQ_STAT_R: LED6.C, R20.2
BQ_SW: C37.2, IC8.19, IC8.20, L1.1
BQ_TS: IC8.11, R15.2, R16.1
BTN_1: IC4.1, S1.2, S1.B1, S1.B2
BTN_2: IC4.3, S2.2, S2.B1, S2.B2
BTN_3: IC4.4, S3.2, S3.B1, S3.B2
BTN_4: IC4.7, S4.2, S4.B1, S4.B2
BTN_5: IC4.6, S5.2, S5.B1, S5.B2
BTN_6: IC4.5, S6.2, S6.B1, S6.B2
BTN_7: IC4.8, S7.2, S7.B1, S7.B2
BTN_8: IC4.10, S8.2, S8.B1, S8.B2
BTN_9: IC4.11, S9.2, S9.B1, S9.B2
BTN_10: IC4.14, S10.2, S10.B1, S10.B2
BTN_11: IC4.13, S11.2, S11.B1, S11.B2
BTN_12: IC4.12, S12.2, S12.B1, S12.B2
BTN_A: IC4.16, S13.2, S13.B1, S13.B2
BTN_B: IC4.17, S15.2, S15.B1, S15.B2
BTN_CALL: IC4.15, S16.2
BTN_END: IC4.2, S17.2
BTN_MENU: IC1.60, S14.2, S14.B1, S14.B2
BTST: C37.1, IC8.21
BT_ANT: C74.2, IC5.20, L5.1
BT_ANT_L: ANT2.1, C75.2, L5.2
CC_!HIB: IC1.124, IC15.2, R25.1
CC_!RESET: C60.2, IC1.118, IC15.32, R73.1
CC_!RTS: IC15.50, R70.1
CC_IRQ: IC1.123, IC15.15, R72.1
CC_RCT_XTAL_N: C100.2, IC15.52, X3.P$1
CC_RESERVED@19: IC15.19, R65.1
CC_RTC_XTAL_P: C101.2, IC15.51, X3.P$2
CC_WLAN_XTAL_: C99.2, IC15.22, X4.3
CC_WLAN_XTAL_P: C98.2, IC15.23, X4.1
CH4: IC1.126, PCB.CH1
DCDC_ANA_SW: IC15.38, L7.2
DCDC_DIG_SW: IC15.43, L9.2
DCDC_PA_SW_N: IC15.41, L8.1
DCDC_PA_SW_P: IC15.40, L8.2
EN0RXI_N: IC1.53, JP7.13
EN0RXI_P: IC1.54, JP7.11
EN0TXO_N: IC1.56, JP7.7
EN0TXO_P: IC1.57, JP7.6
ETHLED0: IC1.63, R1.2
ETHLED0_R: JP7.3, R1.1
ETHLED1: IC1.61, R2.2
ETHLED1_R: JP7.5, R2.1
FET: IC1.110, Q2.1, R59.1
FET_OUT: LED5.K, PCB.FET, Q2.3
FLASH_!CS: IC14.1, IC15.14, JP8.2, R67.1
FLASH_CLK: IC14.6, IC15.11, JP8.3
FLASH_MISO: IC14.2, IC15.13, JP8.1
FLASH_MOSI: IC14.5, IC15.12, JP8.4
FLASH_PU: IC14.3, IC14.7, R66.2
GMS_ANT_L: C73.2, D2.1, J4.ANT, L3.2
GND: ANT1.2, ANT1.3, ANT1.4, ANT2.2, ANT2.3, ANT2.4, C1.2, C2.1, C3.1, C4.1, C5.1, C6.1, C7.1, C8.1, C9.1, C10.1, C11.1, C12.1, C13.1, C14.1, C15.1, C16.1, C17.1, C18.1, C19.1, C20.1, C21.1, C22.1, C23.1, C24.1, C25.1, C26.1, C27.1, C28.1, C29.-, C30.1, C31.1, C32.-, C33.2, C34.2, C35.2, C36.2, C38.1, C39.1, C40.2, C41.2, C42.1, C43.1, C44.2, C45.1, C46.2, C47.2, C48.1, C49.1, C50.1, C51.1, C53.2, C54.2, C55.2, C57.2, C58.2, C59.1, C60.1, C61.2, C62.2, C63.2, C65.2, C66.2, C67.2, C69.2, C70.1, C71.1, C72.1, C73.1, C74.1, C75.1, C76.1, C77.1, C78.1, C84.2, C85.2, C86.2, C87.2, C88.2, C89.2, C90.2, C91.2, C92.2, C93.2, C94.2, C95.2, C96.2, C97.2, C98.1, C99.1, C100.1, C101.1, C102.2, C104.2, D1.A, D2.2, FL1.GND@2, FL1.GND@4, IC1.10, IC1.17, IC1.48, IC1.55, IC1.58, IC1.80, IC1.114, IC2.6, IC2.12, IC2.28, IC2.41, IC2.46, IC2.52, IC2.54, IC3.3, IC3.5, IC4.9, IC4.18, IC4.23, IC4.24, IC4.25, IC5.8, IC5.13, IC5.19, IC5.21, IC5.27, IC5.30, IC5.31, IC5.33, IC5.36, IC5.37, IC6.4, IC7.3, IC8.17, IC8.18, IC8.25, IC9.2, IC9.3, IC9.PAD, IC10.3, IC11.4, IC12.7, IC13.7, IC13.PAD, IC14.4, IC15.PAD, J1.C4, J1.C5, J1.GND1, J1.GND2, J1.GND3, J1.GND4, J1.GND5, J1.GND6, J2.6, J2.11, J2.12, J2.13, J2.14, J2.15, J2.16, J2.17, J2.18, J2.19, J2.20, J2.21, J2.22, J2.23, J2.24, J2.25, J2.26, J2.27, J2.28, J2.29, J2.30, J2.31, J2.32, J2.43, J2.48, J2.49, J2.50, J3.3, J3.5, J3.9, J5.1, JP2.1, JP3.1, JP4.5, JP7.1, JP7.2, JP7.4, JP9.1, LED1.3, LED2.3, LED3.C, LED4.C, PCB.GND, Q1.2, Q2.2, Q8.4, Q8.EP2, R3.2, R7.2, R15.1, R17.2, R19.2, R25.2, R30.2, R38.2, R39.2, R40.2, R51.2, R55.1, R59.2, R61.2, R62.2, R63.2, R64.2, R65.2, R70.2, R71.2, R72.2, S1.1, S1.A1, S1.A2, S2.1, S2.A1, S2.A2, S3.1, S3.A1, S3.A2, S4.1, S4.A1, S4.A2, S5.1, S5.A1, S5.A2, S6.1, S6.A1, S6.A2, S7.1, S7.A1, S7.A2, S8.1, S8.A1, S8.A2, S9.1, S9.A1, S9.A2, S10.1, S10.A1, S10.A2, S11.1, S11.A1, S11.A2, S12.1, S12.A1, S12.A2, S13.1, S13.A1, S13.A2, S14.1, S14.A1, S14.A2, S15.1, S15.A1, S15.A2, S16.1, S17.1, S18.2, S19.1, S20.1, U1.GND, U2.2, U2.4, X2.2, X2.4, X4.2, X4.4
GSM_ANT: C72.2, IC5.32, L3.1
I2C5_EXT_SCL: IC1.121, PCB.SCL, R24.1
I2C5_EXT_SDA: IC1.120, PCB.SDA, R23.1
I2C9_SCL: IC1.33, IC4.19, IC8.5, IC9.4, R22.1, U2.1
I2C9_SDA: IC1.34, IC4.20, IC8.6, IC9.6, R21.1, U2.6
JOY_CEN: IC1.72, SW1.CTR
JOY_DOWN: IC1.74, SW1.D
JOY_LEFT: IC1.73, SW1.C
JOY_RIGHT: IC1.91, SW1.B
JOY_UP: IC1.71, SW1.A
LCD_!RST: IC1.111, J2.10
LCD_DCX: IC1.20, J2.36
LCD_TEAR: IC1.21, J2.39
LED1: IC1.86, R12.2
LED1_R: LED3.A, R12.1
LED2: IC1.85, R14.2
LED2_R: LED4.A, R14.1
LED5_R: LED5.A, R11.1
LEDK: Q8.1, Q8.2, Q8.5, Q8.6, Q8.EP1, R44.1, R47.1, R48.1, R49.1
LEDK1: J2.2, R47.2
LEDK2: J2.3, R48.2
LEDK3: J2.4, R49.2
LEDK4: J2.5, R44.2
MIC_MUX_N: IC5.10, IC12.9, IC12.11
MIC_MUX_P: IC5.9, IC12.1, IC12.3
MIC_N: C52.2, C53.1, C55.1, C56.2, S22.6, U4.-
MIC_P: C52.1, C54.1, C56.1, C57.1, S22.3, U4.+
MIC_PWM_AMP: C79.1, C80.2, C81.2, IC11.1, IC11.2
MIC_PWM_AMP_+: C78.2, IC11.3, R52.2
MIC_PWM_N: C80.1, IC12.8, R54.1
MIC_PWM_P: C81.1, IC12.4, R54.2
MIC_PWM_R: C79.2, R52.1, R53.1
MIC_SWITCHED_N: IC12.10, S22.5
MIC_SWITCHED_P: IC12.2, S22.2
MUX_A: IC1.105, IC12.12, IC12.13, R56.1
MUX_B: IC1.106, IC12.5, IC12.6, R55.2
NETLIGHT_R: IC5.41, R42.2
OSC0: C16.2, IC1.88, X2.1
OSC1: IC1.89, R6.1
OSC1_R: C17.2, R6.2, X2.3
POWER_SWITCH: Q3.4, R13.1, S18.3
PWM0_LCD_BLIGHT: IC1.42, Q8.3
PWM3_MIC_PWM: IC1.45, R53.2
PWR_KEY_FET: IC5.39, Q1.3
RBIAS+: IC1.59, R3.1
SDRAM_!CAS: IC1.83, IC2.17
SDRAM_!CS: IC1.103, IC2.19
SDRAM_!RAS: IC1.84, IC2.18
SDRAM_!WE: IC1.92, IC2.16
SDRAM_A0: IC1.29, IC2.2, IC2.23
SDRAM_A1: IC1.30, IC2.4, IC2.24
SDRAM_A2: IC1.31, IC2.5, IC2.25
SDRAM_A3: IC1.32, IC2.7, IC2.26
SDRAM_A4: IC1.22, IC2.8, IC2.29
SDRAM_A5: IC1.23, IC2.10, IC2.30
SDRAM_A6: IC1.24, IC2.11, IC2.31
SDRAM_A7: IC1.25, IC2.13, IC2.32
SDRAM_A8: IC1.40, IC2.33, IC2.42
SDRAM_A9: IC1.41, IC2.34, IC2.44
SDRAM_A10: IC1.50, IC2.22, IC2.45
SDRAM_A11: IC1.49, IC2.35, IC2.47
SDRAM_A12: IC1.75, IC2.36, IC2.48
SDRAM_BA0: IC1.76, IC2.20, IC2.50
SDRAM_BA1: IC1.77, IC2.21, IC2.51
SDRAM_CKE: IC1.104, IC2.37
SDRAM_CLK: IC1.62, IC2.38
SDRAM_D15: IC1.78, IC2.53
SDRAM_DQMH: IC1.82, IC2.39
SDRAM_DQML: IC1.81, IC2.15
SIM_CLK: IC10.2, J1.C3, R27.2
SIM_CLK_R: C49.2, IC5.16, R27.1
SIM_CTS: R34.1, TP4.TP
SIM_CTS_R: IC5.4, R34.2
SIM_DATA: IC10.1, J1.C7, R26.2
SIM_DATA_R: C50.2, IC5.15, R26.1
SIM_DCD: R33.1, TP3.TP
SIM_DCD_R: IC5.5, R33.2
SIM_DET: IC5.14, J1.C8, R29.2
SIM_DTR: R31.1, TP2.TP
SIM_DTR_R: IC5.6, R31.2, R40.1
SIM_D_N: IC5.26, JP9.2
SIM_D_P: IC5.25, JP9.3
SIM_NETLIGHT: IC1.108, R42.1
SIM_PWR_KEY: IC1.109, Q1.1, R30.1
SIM_RI_R: IC5.7, R32.2
SIM_RST: IC10.4, J1.C2, R28.2
SIM_RST_R: C48.2, IC5.17, R28.1
SIM_RTS: R35.1, TP5.TP
SIM_RTS_R: IC5.3, R35.2, R39.1
SIM_RXD_R: IC5.2, R37.2, R38.1
SIM_STATUS: IC1.107, R41.1
SIM_STATUS_R: IC5.42, R41.2
SIM_TXD_R: IC5.1, R36.2
SIM_VBUS: IC5.24, JP9.4
SIM_VDD: C51.2, IC5.18, IC10.5, J1.C1
SOP0: IC15.35, R64.1
SOP1: IC15.34, R63.1
SOP2: IC15.21, R62.1
SPK_AMP_N: IC13.8, U5.-
SPK_AMP_P: IC13.5, U5.+
SPK_N: C64.2, C65.1, C67.1, C68.2, C82.2, IC5.12, R43.1
SPK_P: C64.1, C66.1, C68.1, C69.1, C83.2, IC5.11, R45.1
SPK_R_N: IC11.5, R45.2, R46.1
SPK_R_P: IC11.6, R43.2, R50.1, R51.1
SSI0_LCD_CLK: IC1.35, J2.37
SSI0_LCD_CS: IC1.36, J2.38
SSI0_LCD_MISO: IC1.38, J2.33
SSI0_LCD_MOSI: IC1.37, J2.34
SSI2_CC_!CS: IC1.3, IC15.8
SSI2_CC_CLK: IC1.4, IC15.5
SSI2_CC_MISO: IC1.1, IC15.7, R71.1
SSI2_CC_MOSI: IC1.2, IC15.6
SSI3_CLK: IC1.5, IC6.6
SSI3_DAT0: IC1.11, IC6.5
SSI3_DAT1: IC1.27, IC6.2
SSI3_DAT2: IC1.46, IC6.3, R10.2
SSI3_DAT3: IC1.119, IC6.7, R9.2
SSI3_FSS: IC1.6, IC6.1
SW: IC3.6, L4.1
T3CCPO_WS2812: IC1.125, LED1.4
TCA_INT: IC1.15, IC4.22
TCK_SWCLK: IC1.100, J3.4, JP4.4
TDI: IC1.98, J3.8
TDO_SWO: IC1.97, J3.6, JP4.6
TMS_SWDIO: IC1.99, J3.2, JP4.2
TPS_FB: C103.2, IC3.2, R60.2, R61.1
T_X: IC1.43, J2.44
T_Y: IC1.44, J2.45
UART1_SIM_RI: IC1.112, R32.1
UART1_SIM_RX: IC1.95, R36.1
UART1_SIM_TX: IC1.96, R37.1
UART3_CC_RX: IC1.116, IC15.55, R68.1
UART3_CC_TX: IC1.117, IC15.57, R69.1
UART5_EXT_RX: IC1.18, PCB.CH3
UART5_EXT_TX: IC1.19, PCB.CH4
USB_D_N: IC1.93, IC7.1, U1.D-
USB_D_P: IC1.94, IC7.2, U1.D+
USB_ID: R8.2, TP6.TP
USB_ID_R: IC7.4, R8.1, U1.ID
USB_SHIELD: C20.2, R7.1, U1.SHIELD, U1.SHIELD@0, U1.SHIELD@1, U1.SHIELD@2, U1.SHIELD@3, U1.SHIELD@5
VBAT: C34.1, C35.1, IC8.13, IC8.14, J5.2
VBATT: C1.1, C29.+, C30.2, C31.2, C32.+, C46.1, D1.C, IC3.1, IC3.7, IC5.34, IC5.35, JP2.2, LED1.1, LED2.1, Q3.1, Q3.2, Q3.3, SJ1.3
VBUS: C41.1, IC7.5, IC8.1, IC8.24, L2.2, LED6.A, TP7.TP
VBUS_L: L2.1, U1.VBUS
VDDC: C6.2, C7.2, C8.2, IC1.87, IC1.115
VDD_ANA: C44.1, C61.1, C62.1, C63.1, IC15.25, IC15.36, IC15.48, L7.1
VDD_DIG_CC: C87.1, C96.1, C97.1, IC15.9, IC15.56, L9.1
VDD_EXT: IC5.40, R29.1
VDD_PA: C84.1, C85.1, C86.1, IC15.33, IC15.42
VDD_PLL: C94.1, IC15.24
VDD_RAM: C95.1, IC15.49
V_UNREG: C40.1, IC8.15, IC8.16, L1.2, PCB.VBATT, Q3.5, Q3.6, Q3.7, Q3.8, Q3.EP, R13.2, R18.2
WFIF_ANT_L: ANT1.1, C77.2, L6.2
WIFI_ANT: C76.2, FL1.OUT, L6.1
WIFI_ANT_F: FL1.IN, IC15.31
WS2812_OUT: JP2.3, LED2.2
WS28212_1: LED1.2, LED2.4
XOSC0: C18.2, IC1.66, X1.P$1
XOSC1: C19.2, IC1.67, X1.P$2

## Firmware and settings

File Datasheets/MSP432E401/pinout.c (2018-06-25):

//*****************************************************************************
//
// Configure the device pins for different signals
//
// Copyright (C) 2014 Texas Instruments Incorporated - http://www.ti.com/ 
// 
// 
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
//    Redistributions of source code must retain the above copyright 
//    notice, this list of conditions and the following disclaimer.
//
//    Redistributions in binary form must reproduce the above copyright
//    notice, this list of conditions and the following disclaimer in the 
//    documentation and/or other materials provided with the   
//    distribution.
//
//    Neither the name of Texas Instruments Incorporated nor the names of
//    its contributors may be used to endorse or promote products derived
//    from this software without specific prior written permission.
//
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
//*****************************************************************************

// This file was automatically generated on 10/06/2018 at 21:30:05
// by TI PinMux version 4.0.1519 
//
//*****************************************************************************

#include <ti/devices/msp432e4/driverlib/driverlib.h>

#include <stdint.h>
#include <stdbool.h>

#include "pinout.h"

//*****************************************************************************
//
//! \addtogroup pinout_api
//! @{
//
//*****************************************************************************

//*****************************************************************************
//
//! Configures the device pins for the customer specific usage.
//!
//! \return None.
//
//*****************************************************************************
void
PinoutSet(void)
{
    //
    // Enable Peripheral Clocks 
    //
	MAP_SysCtlPeripheralEnable(SYSCTL_PERIPH_GPIOA);
	MAP_SysCtlPeripheralEnable(SYSCTL_PERIPH_GPIOB);
	MAP_SysCtlPeripheralEnable(SYSCTL_PERIPH_GPIOC);
	MAP_SysCtlPeripheralEnable(SYSCTL_PERIPH_GPIOD);
	MAP_SysCtlPeripheralEnable(SYSCTL_PERIPH_GPIOE);
	MAP_SysCtlPeripheralEnable(SYSCTL_PERIPH_GPIOF);
	MAP_SysCtlPeripheralEnable(SYSCTL_PERIPH_GPIOG);
	MAP_SysCtlPeripheralEnable(SYSCTL_PERIPH_GPIOH);
	MAP_SysCtlPeripheralEnable(SYSCTL_PERIPH_GPIOJ);
	MAP_SysCtlPeripheralEnable(SYSCTL_PERIPH_GPIOK);
	MAP_SysCtlPeripheralEnable(SYSCTL_PERIPH_GPIOL);
	MAP_SysCtlPeripheralEnable(SYSCTL_PERIPH_GPIOM);
	MAP_SysCtlPeripheralEnable(SYSCTL_PERIPH_GPION);
	MAP_SysCtlPeripheralEnable(SYSCTL_PERIPH_GPIOP);
	MAP_SysCtlPeripheralEnable(SYSCTL_PERIPH_GPIOQ);

    //
    // Configure the GPIO Pin Mux for PE3
	// for AIN0
    //
	MAP_GPIOPinTypeADC(GPIO_PORTE_BASE, GPIO_PIN_3);

	//
	// Unlock the Port Pin and Set the Commit Bit
	//
	GPIOD->GPIO_O_LOCK = GPIO_LOCK_KEY;
	GPIOD->GPIO_O_CR   |= GPIO_PIN_7;
	GPIOD->GPIO_O_LOCK = 0x0;
	
    //
    // Configure the GPIO Pin Mux for PD7
	// for AIN4
    //
	MAP_GPIOPinTypeADC(GPIO_PORTD_BASE, GPIO_PIN_7);

    //
    // Configure the GPIO Pin Mux for PE2
	// for AIN1
    //
	MAP_GPIOPinTypeADC(GPIO_PORTE_BASE, GPIO_PIN_2);

    //
    // Configure the GPIO Pin Mux for PD6
	// for AIN5
    //
	MAP_GPIOPinTypeADC(GPIO_PORTD_BASE, GPIO_PIN_6);

    //
    // Configure the GPIO Pin Mux for PL0
	// for EPI0S16
    //
	MAP_GPIOPinConfigure(GPIO_PL0_EPI0S16);
	GPIOPinTypeEPI(GPIO_PORTL_BASE, GPIO_PIN_0);

    //
    // Configure the GPIO Pin Mux for PG0
	// for EPI0S11
    //
	MAP_GPIOPinConfigure(GPIO_PG0_EPI0S11);
	GPIOPinTypeEPI(GPIO_PORTG_BASE, GPIO_PIN_0);

    //
    // Configure the GPIO Pin Mux for PA6
	// for EPI0S8
    //
	MAP_GPIOPinConfigure(GPIO_PA6_EPI0S8);
	GPIOPinTypeEPI(GPIO_PORTA_BASE, GPIO_PIN_6);

    //
    // Configure the GPIO Pin Mux for PH1
	// for EPI0S1
    //
	MAP_GPIOPinConfigure(GPIO_PH1_EPI0S1);
	GPIOPinTypeEPI(GPIO_PORTH_BASE, GPIO_PIN_1);

    //
    // Configure the GPIO Pin Mux for PP3
	// for EPI0S30
    //
	MAP_GPIOPinConfigure(GPIO_PP3_EPI0S30);
	GPIOPinTypeEPI(GPIO_PORTP_BASE, GPIO_PIN_3);

    //
    // Configure the GPIO Pin Mux for PL3
	// for EPI0S19
    //
	MAP_GPIOPinConfigure(GPIO_PL3_EPI0S19);
	GPIOPinTypeEPI(GPIO_PORTL_BASE, GPIO_PIN_3);

    //
    // Configure the GPIO Pin Mux for PM0
	// for EPI0S15
    //
	MAP_GPIOPinConfigure(GPIO_PM0_EPI0S15);
	GPIOPinTypeEPI(GPIO_PORTM_BASE, GPIO_PIN_0);

    //
    // Configure the GPIO Pin Mux for PM2
	// for EPI0S13
    //
	MAP_GPIOPinConfigure(GPIO_PM2_EPI0S13);
	GPIOPinTypeEPI(GPIO_PORTM_BASE, GPIO_PIN_2);

    //
    // Configure the GPIO Pin Mux for PB3
	// for EPI0S28
    //
	MAP_GPIOPinConfigure(GPIO_PB3_EPI0S28);
	GPIOPinTypeEPI(GPIO_PORTB_BASE, GPIO_PIN_3);

    //
    // Configure the GPIO Pin Mux for PG1
	// for EPI0S10
    //
	MAP_GPIOPinConfigure(GPIO_PG1_EPI0S10);
	GPIOPinTypeEPI(GPIO_PORTG_BASE, GPIO_PIN_1);

    //
    // Configure the GPIO Pin Mux for PK5
	// for EPI0S31
    //
	MAP_GPIOPinConfigure(GPIO_PK5_EPI0S31);
	GPIOPinTypeEPI(GPIO_PORTK_BASE, GPIO_PIN_5);

    //
    // Configure the GPIO Pin Mux for PP2
	// for EPI0S29
    //
	MAP_GPIOPinConfigure(GPIO_PP2_EPI0S29);
	GPIOPinTypeEPI(GPIO_PORTP_BASE, GPIO_PIN_2);

    //
    // Configure the GPIO Pin Mux for PH3
	// for EPI0S3
    //
	MAP_GPIOPinConfigure(GPIO_PH3_EPI0S3);
	GPIOPinTypeEPI(GPIO_PORTH_BASE, GPIO_PIN_3);

    //
    // Configure the GPIO Pin Mux for PC5
	// for EPI0S6
    //
	MAP_GPIOPinConfigure(GPIO_PC5_EPI0S6);
	GPIOPinTypeEPI(GPIO_PORTC_BASE, GPIO_PIN_5);

    //
    // Configure the GPIO Pin Mux for PA7
	// for EPI0S9
    //
	MAP_GPIOPinConfigure(GPIO_PA7_EPI0S9);
	GPIOPinTypeEPI(GPIO_PORTA_BASE, GPIO_PIN_7);

    //
    // Configure the GPIO Pin Mux for PH0
	// for EPI0S0
    //
	MAP_GPIOPinConfigure(GPIO_PH0_EPI0S0);
	GPIOPinTypeEPI(GPIO_PORTH_BASE, GPIO_PIN_0);

    //
    // Configure the GPIO Pin Mux for PC4
	// for EPI0S7
    //
	MAP_GPIOPinConfigure(GPIO_PC4_EPI0S7);
	GPIOPinTypeEPI(GPIO_PORTC_BASE, GPIO_PIN_4);

    //
    // Configure the GPIO Pin Mux for PL1
	// for EPI0S17
    //
	MAP_GPIOPinConfigure(GPIO_PL1_EPI0S17);
	GPIOPinTypeEPI(GPIO_PORTL_BASE, GPIO_PIN_1);

    //
    // Configure the GPIO Pin Mux for PM1
	// for EPI0S14
    //
	MAP_GPIOPinConfigure(GPIO_PM1_EPI0S14);
	GPIOPinTypeEPI(GPIO_PORTM_BASE, GPIO_PIN_1);

    //
    // Configure the GPIO Pin Mux for PC7
	// for EPI0S4
    //
	MAP_GPIOPinConfigure(GPIO_PC7_EPI0S4);
	GPIOPinTypeEPI(GPIO_PORTC_BASE, GPIO_PIN_7);

    //
    // Configure the GPIO Pin Mux for PL2
	// for EPI0S18
    //
	MAP_GPIOPinConfigure(GPIO_PL2_EPI0S18);
	GPIOPinTypeEPI(GPIO_PORTL_BASE, GPIO_PIN_2);

    //
    // Configure the GPIO Pin Mux for PM3
	// for EPI0S12
    //
	MAP_GPIOPinConfigure(GPIO_PM3_EPI0S12);
	GPIOPinTypeEPI(GPIO_PORTM_BASE, GPIO_PIN_3);

    //
    // Configure the GPIO Pin Mux for PC6
	// for EPI0S5
    //
	MAP_GPIOPinConfigure(GPIO_PC6_EPI0S5);
	GPIOPinTypeEPI(GPIO_PORTC_BASE, GPIO_PIN_6);

    //
    // Configure the GPIO Pin Mux for PH2
	// for EPI0S2
    //
	MAP_GPIOPinConfigure(GPIO_PH2_EPI0S2);
	GPIOPinTypeEPI(GPIO_PORTH_BASE, GPIO_PIN_2);
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

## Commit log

2017-11-19 First commit, bring in last years parts lbr and setting up blank files, Licence and readme
    [Mk4 Prototype.brd, Mk4 Prototype.sch]
2017-11-24 TI Tiva datasheets
    [pin-table-TM4C1290NCPDT.csv]
2018-03-25 started mk3 sim breakout
    [sim-breakout.sch]
2018-04-07 started dev board 1
    [dev-board1.brd, dev-board1.sch]
2018-04-08 adding power parts
2018-04-08 adding power supply
    [dev-board1.brd, dev-board1.sch]
2018-04-08 connecting some serial interfaces
    [dev-board1.brd, dev-board1.sch]
2018-04-09 some more connections done
    [dev-board1.brd, dev-board1.sch]
2018-04-10 adding magjack
    [dev-board1.brd, dev-board1.sch]
2018-04-10 changing to cc3120miod
    [dev-board1.brd]
2018-04-10 all major connections done
    [dev-board1.brd, dev-board1.sch]
2018-04-10 testpoints added
    [dev-board1.brd, dev-board1.sch]
2018-04-10 a few single testpoints
    [dev-board1.brd, dev-board1.sch]
2018-04-11 ready to start routing
    [dev-board1.brd, dev-board1.sch]
2018-04-14 load of routing
    [dev-board1.brd]
2018-04-15 getting closer...
    [dev-board1.brd, dev-board1.sch]
2018-04-15 load of routing again
    [dev-board1.brd]
2018-04-15 load of routing again again
    [dev-board1.brd]
2018-04-16 load of routing again again again
    [dev-board1.brd, dev-board1.sch]
2018-04-25 adding extra audio paths
    [dev-board1.brd, dev-board1.sch]
2018-04-26 getting close
    [dev-board1.brd, dev-board1.sch]
2018-04-27 zero airwires
    [dev-board1.brd, dev-board1.sch]
2018-04-27 some silk work
    [dev-board1.brd]
2018-04-29 finishing touches...
    [dev-board1.brd, dev-board1.sch]
2018-04-29 some tweaks
    [dev-board1.brd]
2018-04-29 silk tweaks
    [dev-board1.brd]
2018-04-29 final prototype 1 (hopefully)
    [dev-board1.brd, dev-board1.sch]
2018-05-11 adding part numbers
    [dev-board1.brd, dev-board1.sch]
2018-05-13 adding final few farnell numbers
    [dev-board1.brd, dev-board1.sch]
2018-05-16 Datasheet swap out
    [MCU0231.0.GBL, MCU0231.0.GBO, MCU0231.0.GBP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]
2018-05-16 Initial shape and some layout ideas
    [Mk4 Prototype.brd, Mk4 Prototype.sch]
2018-05-16 Drop in a few more parts and identified some options for Spk, MIC and antennas
    [Mk4 Prototype.brd, Mk4 Prototype.sch]
2018-05-17 NIght 2
    [Mk4 Prototype.brd, Mk4 Prototype.sch]
2018-05-21 Day 3
    [Mk4 Prototype.brd]
2018-05-22 Schematic should now have all the parts
    [Mk4 Prototype.brd]
2018-05-22 Tweaks for BOM
    [Mk4 Prototype.brd]
2018-05-22 Tweaks for BOM 2
    [Mk4 Prototype.brd]
2018-05-25 Bom based updates
    [Mk4 Prototype.brd]
2018-05-28 Connect some pins, try out TI Booster pack headers and add MIC disconnect
    [Mk4 Prototype.brd]
2018-05-29 Night 4, Swap out CC3120MOD for CC3130R Getting some routing done
    [Mk4 Prototype.brd]
2018-05-30 Added tmp102, swapped out TPS62, more routing
    [Mk4 Prototype.brd]
2018-05-31 Day 5? routing done for prototype
    [Mk4 Prototype.brd]
2018-05-31 Gerber tweaks
    [Mk4 Prototype.brd]
2018-05-31 Cam job, some datasheets, out of date pinmux project
    [CC3120_BOM.xls]
2018-06-25 Lots of changes for the final board design
    [Mk4 Final.brd]
2018-06-25 Datasheets, lots of them
    [summary.csv]
2018-06-28 Final design before panel
    [Mk4 Final.brd]
2018-06-29 Final tweeks and panel as went to mfg
    [Mk4 Final.brd]
2018-07-01 Correct schematic pdfs
2018-07-30 tweaks from final panel layout
    [Mk4 Final a.brd, Mk4 Final.brd]
2018-07-30 DXF: outline + final artwork for case design
2018-08-21 Few DNP's and schematic for print
    [Mk4 Final a.brd]
2018-08-28 Last few tweaks
    [Mk4 Final.brd]
2018-08-28 Big clean up
    [Mk4 Final.brd, Mk4 Prototype.brd]
2018-08-30 Add Battery datasheet
2018-09-09 rename battery datasheet so it can be checked out on windows, fixes #2

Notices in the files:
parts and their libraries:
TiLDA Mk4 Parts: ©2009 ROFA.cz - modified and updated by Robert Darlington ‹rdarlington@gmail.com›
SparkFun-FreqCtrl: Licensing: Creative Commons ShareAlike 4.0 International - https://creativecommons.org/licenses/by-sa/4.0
